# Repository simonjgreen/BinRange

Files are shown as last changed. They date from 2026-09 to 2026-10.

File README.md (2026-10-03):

# BinRange

The calendar says it's bin night. Have the bins actually made it to the kerb?

BinRange gives each bin a battery-powered UWB tag. A fixed anchor measures its
distance and publishes per-tag telemetry to Home Assistant over MQTT. Moving
bins report frequently; stationary bins check in slowly. Home Assistant can
combine that physical evidence with collection dates to show what needs attention.

Collection scheduling for the Home Assistant automations leverages the brilliant
[Waste Collection Schedule](https://github.com/mampfes/hacs_waste_collection_schedule)
integration, available through [HACS](https://hacs.xyz/). It supplies the collection
calendar; BinRange supplies the bin's movement, distance and health.
A [configurable reminder example](examples/home-assistant/README.md) combines the
calendar with fresh Home and observed or presumed Out states for put-out and bring-in notifications.
The optional [tipping package](examples/home-assistant/README.md#tipping-triggered-emptying-messages)
adds the emptying message below when tipping-capable tag and anchor firmware are
installed: a tilt beyond 90 degrees is assumed emptied, and due bins confidently
Out are grouped over 60 seconds. Scheduled reminders remain the fallback.

## Phone reminders

**Bins out tomorrow**

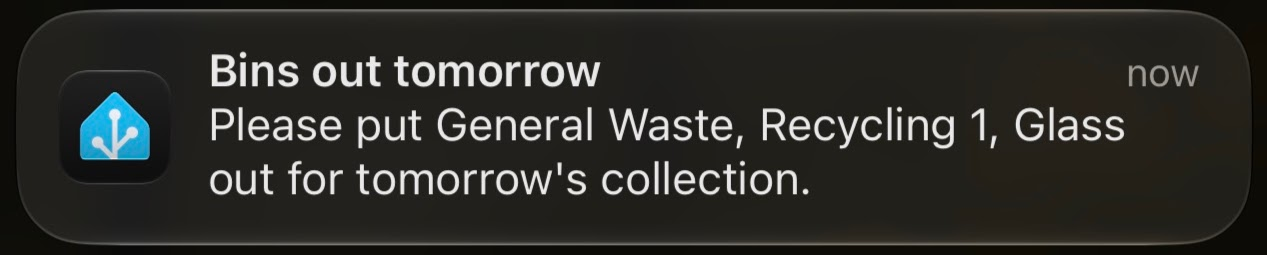
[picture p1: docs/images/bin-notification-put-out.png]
Home Assistant notification reminding you to put General Waste, Recycling 1 and Glass out for tomorrow's collection


**You have still not put the bins out!**

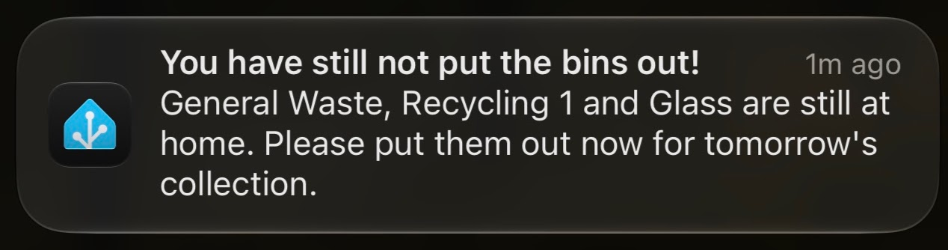
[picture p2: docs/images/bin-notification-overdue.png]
Home Assistant notification warning that General Waste, Recycling 1 and Glass are still at home and need putting out


**The bins have just been emptied**

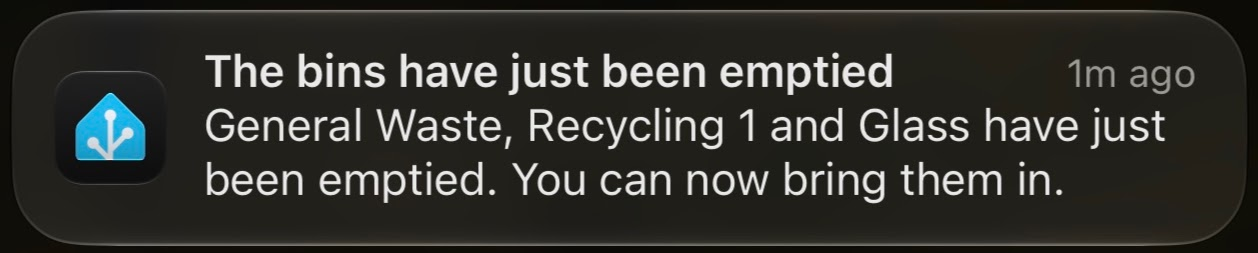
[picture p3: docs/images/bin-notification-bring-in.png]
Home Assistant notification saying General Waste, Recycling 1 and Glass have been emptied and can now be brought in


## The hardware

The main anchor is now wall mounted in its enclosure, all six bins have tags,
and the Home Assistant setup is in use.

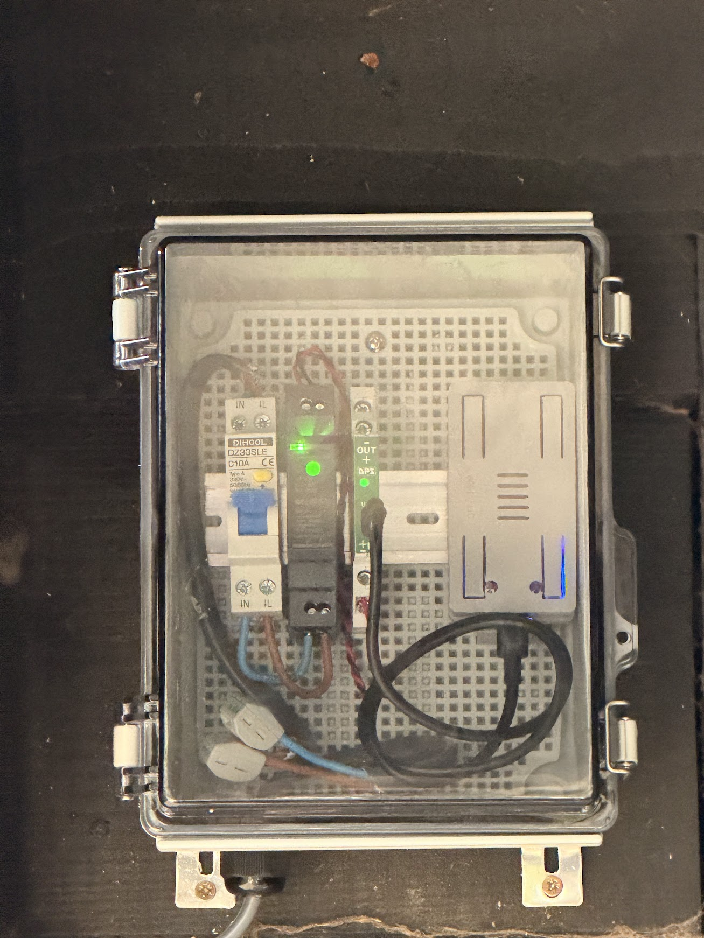
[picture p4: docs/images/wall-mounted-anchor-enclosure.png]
Installed BinRange anchor in its printed case, mounted alongside the power components inside a clear-lidded wall enclosure


*The installed anchor enclosure, photographed by the project owner.*

The anchor has a custom printable case; the battery tags attach to the bins.
These renders show the accepted **v7.1.0 WROVER case**, using the actual print
meshes. Colours and surface finish are illustrative.

| Closed case | Inside the case |
| --- | --- |
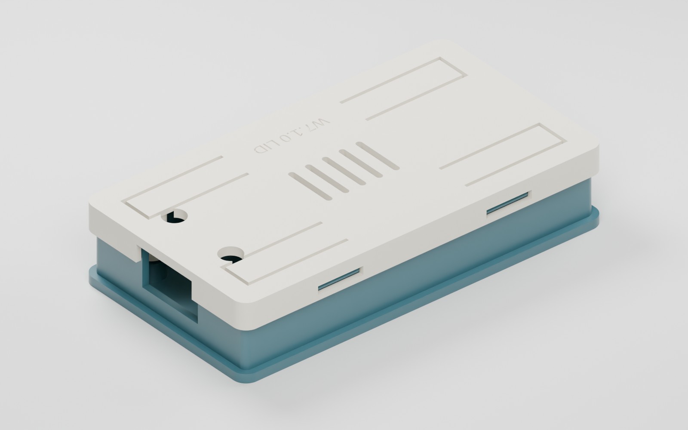
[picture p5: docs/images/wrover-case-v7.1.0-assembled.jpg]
Studio render of the assembled WROVER case, with a petrol-blue base and a warm light lid
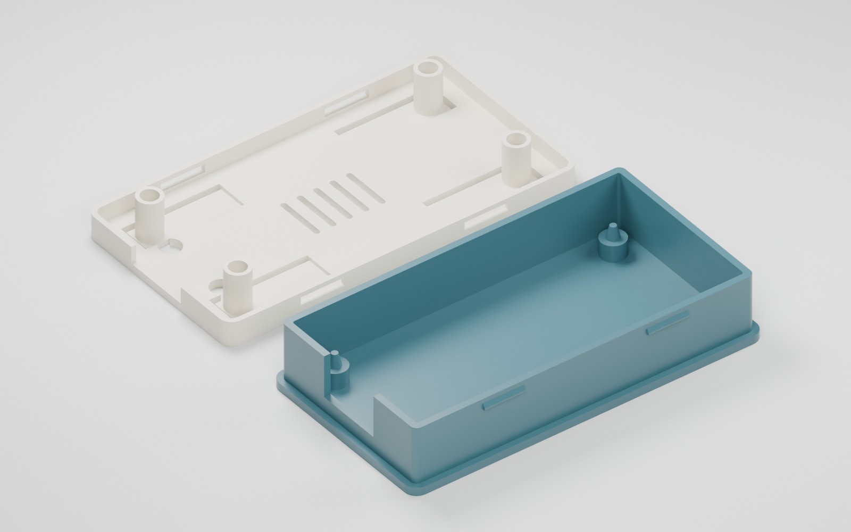
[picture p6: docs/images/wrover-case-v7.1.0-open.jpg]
Studio render of the separate base and lid showing the PCB locating cones, spring supports and ventilation slots
|  |  |

[Case design, version history and print downloads](hardware/wrover-case/README.md).
The separate v7.2.0 DIN rail variant remains experimental.

Installed KKM K4W tags, shown on three different bins:

| Under a wheelie-bin rim | On a food caddy | Under a brown-bin rim |
| --- | --- | --- |
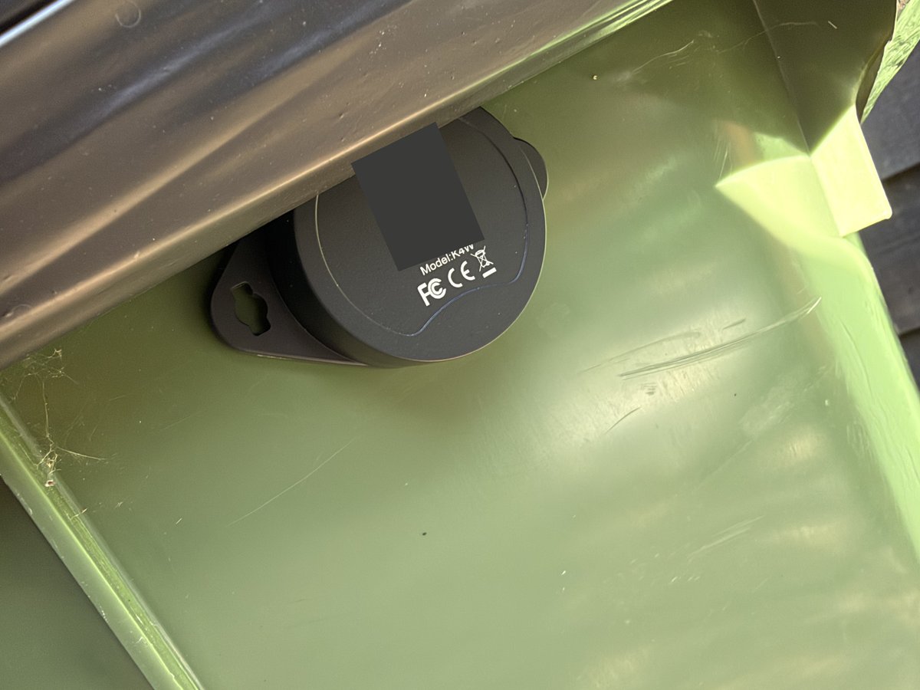
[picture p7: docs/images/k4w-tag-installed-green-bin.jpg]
K4W tag mounted beneath the rim of a green wheelie bin
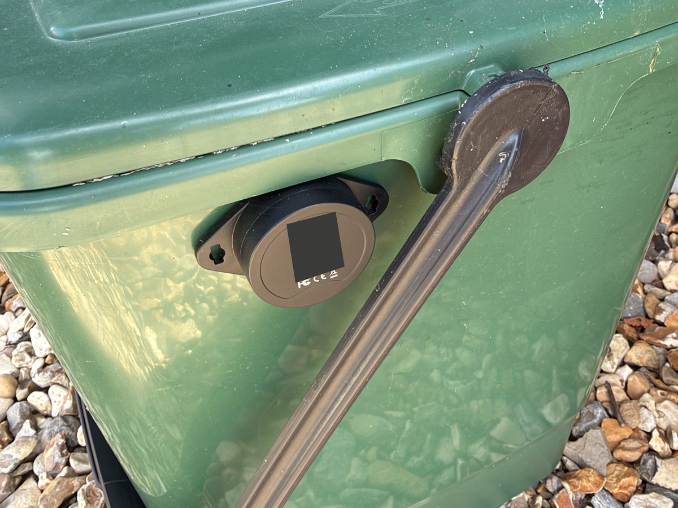
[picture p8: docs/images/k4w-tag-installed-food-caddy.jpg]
K4W tag attached to a green food caddy near its carrying handle
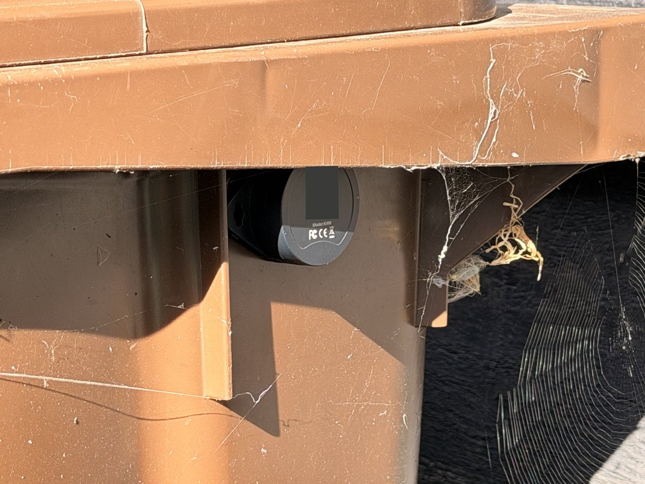
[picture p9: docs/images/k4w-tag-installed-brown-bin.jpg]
K4W tag mounted below the rear rim of a brown wheelie bin
|  |  |  |

| Anchor board | The installation |
| --- | --- |
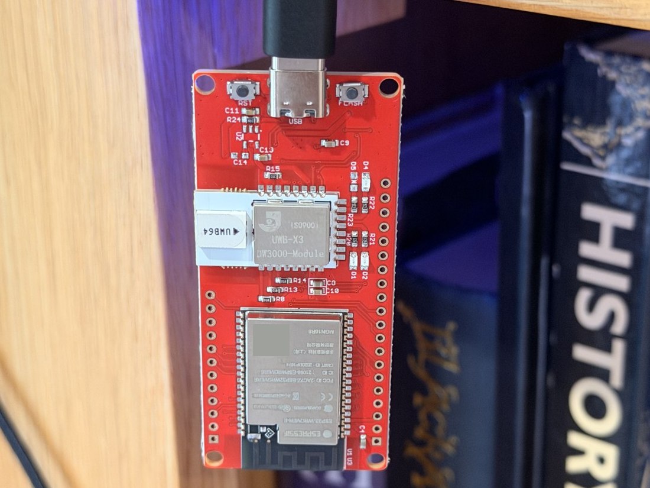
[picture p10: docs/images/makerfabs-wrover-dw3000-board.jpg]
Makerfabs ESP32-WROVER anchor board with USB connected, DW3000 radio module and UWB antenna visible
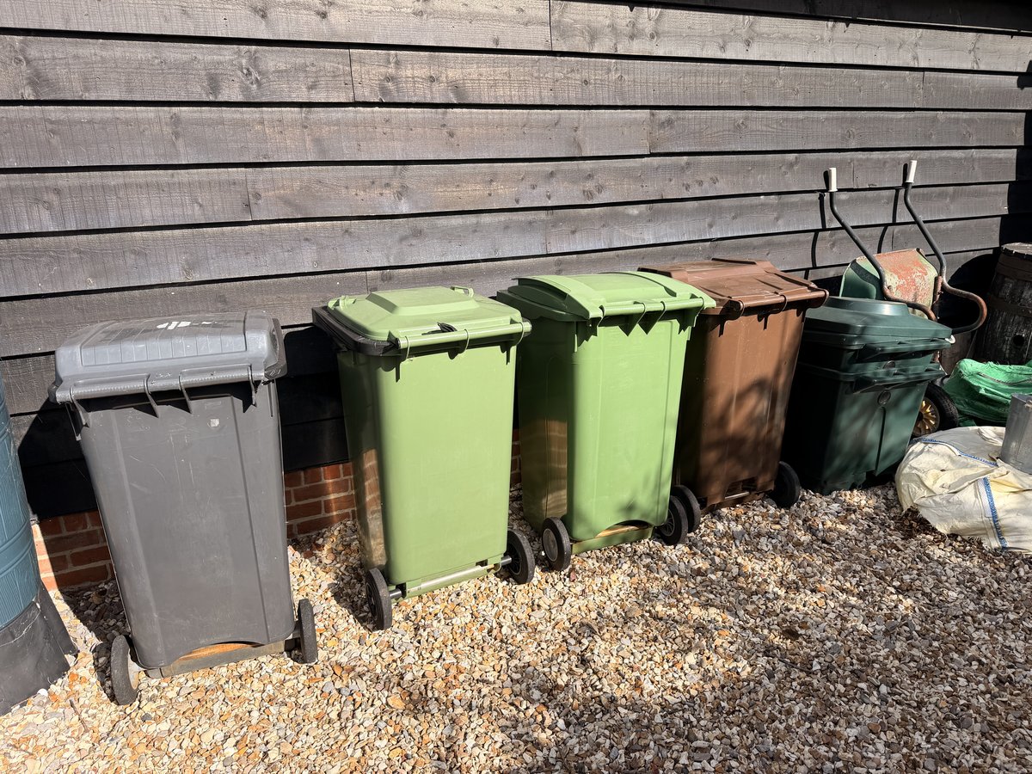
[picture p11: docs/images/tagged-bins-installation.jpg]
A row of household bins in the outdoor installation
|  |  |

*Real installation and development-board photos. Visible device QR codes and
identifiers are obscured; published copies contain no embedded metadata. Mounting
photos document the prototype, not a weatherproofing or coverage guarantee.*

## See it working

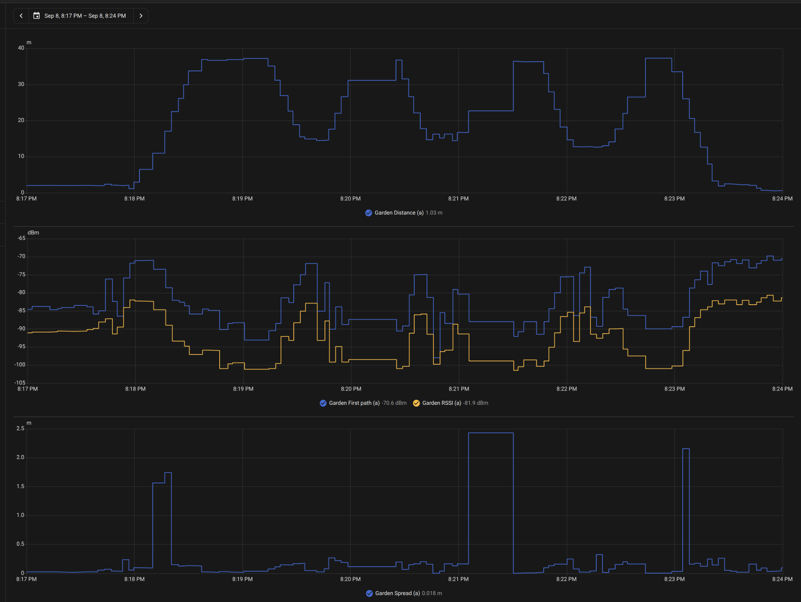
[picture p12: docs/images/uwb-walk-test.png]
UWB outdoor walk: distance rises and falls, with first-path, RSSI and range-spread traces


*Real development walk-test capture using two WROVER boards. Reliable readings
reached roughly 30 m in that setup, with intermittent readings beyond it.
This is not a guaranteed range for a packaged tag or a mounted bin.*

<details>
<summary>Test-phase web interface: live range, link diagnostics and radio tuning</summary>

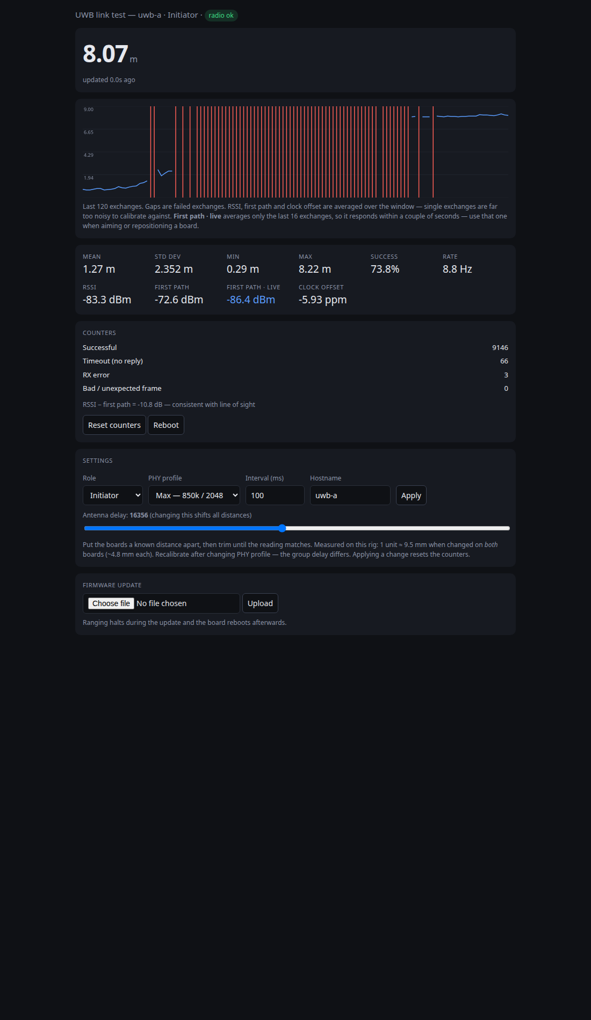
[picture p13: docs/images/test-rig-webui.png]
Early test-rig web interface showing measured distance, exchange history, signal diagnostics and configurable radio settings


*Historical SS-TWR test interface, not the current deployment UI. Its success
percentage and signal interpretation are test-rig diagnostics—not an end-to-end
delivery guarantee or a validated obstruction detector.*

</details>

The important distinction is between **a bin that is home** and **a bin whose
last known reading was home**. Stale data stays visible as stale; silence must
not be mistaken for a bin being put out or brought back. Once a departure has
been observed, location can remain Out through lost reception until a fresh
Home reading confirms its return; reception health remains separate.

## How it fits together

```text
Battery tags ──UWB──> Fixed anchor ──MQTT──> Home Assistant
    ▲                    │                     ▲
    └── signed BLE OTA ──┘                     │
                                 Waste Collection Schedule
```

- **Tags:** KKM K4W, nRF52833 + DW3110 + LIS3DH; custom Zephyr firmware.
- **Anchor:** Makerfabs ESP32-WROVER / DW3000; custom Arduino firmware with MQTT,
  local web administration and signed-tag-update delivery.
- **Home Assistant:** one device per tag plus anchor diagnostics; separate daily
  status and technical monitoring views.
- **Maintenance:** signed application updates, local health confirmation and
  rollback; SWD remains the first-installation/rescue path.
- **No ESPHome component or additional BinRange server.** Ranging does not depend
  on the MQTT broker or Home Assistant being available.

## Status and limitations

This is an **experimental, working field prototype**, not a turnkey product.
A six-tag installation is in use, with the anchor wall mounted, tags on all bins
and Home Assistant configured. Multi-week battery life, installed coverage and
unattended BLE maintenance still need longer-term field evidence.

Default tag behavior is immediate motion reporting, about 5 s while moving,
settling after 30 s quiet, and a 10 min stationary check-in. Motion sensitivity
is tunable; missing-check-in monitoring is separate from short-term range
freshness. The initial absence threshold is six hours. Paired tags expose
stationary and moving check-in interval controls in Home Assistant; the anchor
applies them over authenticated Bluetooth and verifies the saved values.
See [check-in interval controls](docs/mqtt.md#changing-tag-check-in-intervals).

One anchor measures **distance, not direction or coordinates**. A Home/Out
distance threshold is site-specific; it cannot distinguish equal-radius places.
Metal, bodies, orientation and mounting affect coverage. Battery voltage is
measured; any percentage derived from it is an estimate, not a fuel gauge.
Do not infer months of battery life from a short voltage trace.

## Build your own

Start with [the setup guide](docs/getting-started.md), then the relevant firmware
instructions. You will need an appropriate UWB anchor, compatible tags, an SWD
programmer, a local MQTT broker and Home Assistant. Review the exact board pinout
and use your own credentials, tag identities and signing key.

| Reference | Purpose |
| --- | --- |
| [Getting started](docs/getting-started.md) | Prerequisites, setup sequence and local configuration |
| [Hardware](docs/hardware.md) | Components, wiring, battery and motion constraints |
| [Printable anchor case](hardware/wrover-case/README.md) | Case renders, version status, source and print files |
| [MQTT / Home Assistant](docs/mqtt.md) | Topics, adoption, freshness and scheduling integration |
| [Collection reminder example](examples/home-assistant/README.md) | Placeholder YAML, phone-group setup and put-out/return reminder behavior |
| [Signed tag build and recovery](firmware/k4w-tag/BUILD.md) | SDK, partitions, signing and safe installation |
| [BLE update contract](docs/tag-updates.md) | Authentication, persistence and recovery invariants |
| [Nesso SWD probe](firmware/nesso-probe/README.md) | Optional programmer build and wiring |
| [Findings](docs/findings.md) | Reusable measured results and their limitations |
| [Roadmap](docs/current-work.md) | Remaining project acceptance work |

## Repository hygiene

The active firmware is in `firmware/anchor` and `firmware/k4w-tag`, with the
shared radio driver in `firmware/shared`. The Nesso probe and `scripts/` contain
programming, recovery and host-test tooling. `firmware/tag-emulator` is a bench
DS-TWR test peer; `firmware/test-rig` is the frozen early SS-TWR experiment.
Neither is required on the installed bins. Older enclosure versions and their
verified archive are retained as design history, with their status recorded in
the [case index](hardware/wrover-case/README.md).

This repository contains reusable source, documentation, synthetic test
identities and selected screenshots. Local addresses, household calendars,
physical tag/casing registers, credentials, signing keys, private captures and
provisioned firmware belong in ignored local storage—not Git.

On an existing working installation, consult ignored
`local-backups/deployment/docs/current-work.md` for its private operating plan
before touching devices. Public examples are not deployment instructions for
someone else's hardware. Do not blindly replay first installation on a paired tag.

BinRange's original code and documentation are licensed under the
[MIT License](LICENSE). Third-party components retain their own licences and
vendor notices. See [third-party notes](docs/third-party.md).

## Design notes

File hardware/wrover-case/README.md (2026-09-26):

# WROVER case — working design v7.1.0

**Working design: [v7.1.0](versions/v7.1.0/README.md), accepted by the user. Both halves remain compatible with v7.0.0.**

[Complete v7.1.0 print package](releases/wrover-case-v7.1.0.zip) · [Full base STL](versions/v7.1.0/exports/wrover-case-v7.1.0-base.stl) · [Full lid STL](versions/v7.1.0/exports/wrover-case-v7.1.0-lid.stl) · [OpenSCAD source](versions/v7.1.0/wrover-case-v7.1.0.scad) · [Preview](versions/v7.1.0/exports/wrover-case-v7.1.0-layout.png)

The user reports v7.0.0 as “really good” and has accepted v7.1.0, with wider locating cones and centred vents, as the working design. No quantified retention, thermal or endurance results have been reported.

| Assembled v7.1.0 | Base and lid interior |
| --- | --- |
| Assembled WROVER case rendered from the v7.1.0 print meshes | Open v7.1.0 case showing PCB locating cones and lid springs |

*Renders of the actual STL geometry; colours and surface finish are illustrative.
The board is omitted to show the case details. [Renderer](tools/render_readme.py).*

**DIN rail candidate: [v7.2.0](versions/v7.2.0/README.md)**, experimental. It is the v7.1.0 base on a dovetail plinth with a separate snap-on TS35 clip. The lid is unchanged. [Base](versions/v7.2.0/exports/wrover-case-v7.2.0-base.stl) · [DIN clip](versions/v7.2.0/exports/wrover-case-v7.2.0-din-clip.stl) · [Print package](releases/wrover-case-v7.2.0.zip)

## Version history

Old names have been normalised without changing the archived geometry. The historical v5.1 is now v5.1.0, for example.

| Version | Closure | Physical result | Base compatibility |
|---|---|---|---|
| v1.0.0 | Original screws | Original board fit check passed; standalone source not found | Not established |
| [v2.0.0](versions/v2.0.0/README.md) | Recessed M2.5 screws | Superseded small-hardware approach | v2 only |
| [v3.0.0](versions/v3.0.0/README.md) | M2 bolts and nuts | Rejected: PLA fits and small hardware impractical | v3 only |
| [v4.0.0](versions/v4.0.0/README.md) | External flexible clips | Pegs and PCB springs worked; lid loose | v4 only |
| [v5.0.0](versions/v5.0.0/README.md) | Internal lip, 0.6 mm hooks | Good fit; insufficient retention | v5 base |
| [v5.1.0](versions/v5.1.0/README.md) | 1.0 mm hooks | Better retention; still pulls off easily | v5 base |
| [v5.2.0](versions/v5.2.0/README.md) | 3.0 mm full-wall hooks | **Failed: both roots broke on insertion** | v5 base |
| [v6.0.0](versions/v6.0.0/README.md) | Torsion-arm catches | CAD checks only; untested, superseded by research direction | v5 base |
| [v7.0.0](versions/v7.0.0/README.md) | Overlapping shells, four shallow beads | **User-tested: “really good”; two refinements requested** | v7.0.0 / v7.1.0 / v7.2.0 halves |
| [v7.1.0](versions/v7.1.0/README.md) | Same closure; 3 mm cone roots, centred vents | **Working design: accepted by user** | v7.0.0 / v7.1.0 / v7.2.0 halves |
| [v7.2.0](versions/v7.2.0/README.md) | v7.1.0 plus dovetail plinth and snap-on TS35 DIN clip | Experimental: CAD checks only | Any v7 lid; lid unchanged |

## Folder and naming rules

```text
wrover-case/
  README.md                  Start here: working version, history, compatibility
  versions.json              Machine-readable version/status index
  versions/v7.1.0/            One self-contained design snapshot
    README.md                Printing, assembly, evidence and limitations
    status.json              Physical status and part hashes
    wrover-case-v7.1.0.scad   Versioned source
    verify_geometry.scad     Collision/engagement checks
    verify_geometry.py       Check runner
    geometry-results.json    Recorded results, not a physical-test certificate
    exports/
      wrover-case-v7.1.0-base.stl
      wrover-case-v7.1.0-lid.stl
      wrover-case-v7.1.0-layout.png
  releases/                  Versioned distribution ZIPs
  tools/                     Shared mesh validation
  sources/                   Board dimensions and original PCB evidence
  research/                  Maker references and design findings
  archive/                   Verified, byte-preserved original file tree ZIP
```

- Use `vMAJOR.MINOR.PATCH`, numerically sorted. Increment **major** for a new closure architecture or incompatible mating geometry; **minor** for a compatible geometry variant; **patch** for corrected exports or manufacturing details with the same intended fit. A patch is still a new printable file, never a silent overwrite.
- Treat delivered sources and print meshes as snapshots. Store subsequent geometry under a new version. Status/physical feedback may be updated without changing geometry.
- Use `wrover-case-v<version>-<part>.<extension>` for printable/downloadable files. Do not use floating `base.stl`, `lid.stl`, `latest`, `final`, or an unqualified `trial` filename.
- Each version directory includes its complete matching base/lid pair, even when a base is unchanged. Equal base hashes document actual reuse. The compatibility table overrides assumptions based on version numbers; historical v6 retained the v5 base.
- Record physical status separately from version: working, experimental, user-tested, partial-success, failed, rejected or superseded. A newer number is not proof of improvement.
- Produce full-case candidates. Small closure coupons are historical only, following the user's printing preference.

## Preserved history

All 67 previously present case files (excluding Python bytecode and the unchanged board/research directories) were preserved and SHA-256 verified in [the original-layout archive](archive/README.md) before reorganisation. This includes prior ZIPs, duplicated aliases, small coupons, previews and historical instructions. Canonical historical source/STL copies retain their original bytes; verification includes were updated to the renamed sources.

The unversioned `case.3mf` and `base.png` could not be assigned a reliable version and remain labelled as unverified historical assets in the archive. No v1 source has been invented. The board evidence remains in `sources/`.

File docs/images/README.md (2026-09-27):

# README hardware images

The public hardware gallery uses the following derivatives. Private originals
and Live Photo videos are not included here.

| Asset | Subject / source |
| --- | --- |
| `wall-mounted-anchor-enclosure.png` | User-supplied photo of the installed anchor enclosure, preserved unchanged |
| `wrover-case-v7.1.0-assembled.jpg` | Accepted v7.1.0 base/lid STL meshes, assembled |
| `wrover-case-v7.1.0-open.jpg` | The same meshes, separated to show their interiors |
| `k4w-tag-installed-green-bin.jpg` | User-supplied installation photo, cropped |
| `k4w-tag-installed-food-caddy.jpg` | User-supplied installation photo, cropped |
| `k4w-tag-installed-brown-bin.jpg` | User-supplied installation photo |
| `tagged-bins-installation.jpg` | User-supplied installation overview |
| `makerfabs-wrover-dw3000-board.jpg` | Existing local development-board photo, cropped |

The case renders are generated with
[`render_readme.py`](../../hardware/wrover-case/tools/render_readme.py), using
Blender 4.5.3, soft studio lighting and illustrative polymer materials. They
preserve the printable geometry. They are not photographs of a manufactured
case. The board is omitted.

The seven JPEGs have photos at most 1200 × 900 pixels and renders at 1600 × 1000.
They are optimized progressive JPEGs. Orientation is baked into the pixels before
export. Each image is copied into a fresh RGB image and encoded without EXIF,
GPS, XMP, IPTC, comments, embedded thumbnails or source colour profiles.

The wall-mounted enclosure photo is the original 1307 × 1742 PNG. Its only PNG
chunk types are IHDR, IDAT and IEND; it has no embedded metadata. The supplied
pixels were inspected and contain no readable device identifiers needing masking.

Readable device QR codes and identifiers are covered with opaque masks before
resizing. The food-caddy crop also excludes the label on its lid. Model names
and regulatory markings remain where possible. Original filenames, capture
timestamps, device identities and local source paths are not recorded here.

For future additions, inspect the pixels as well as metadata: strip metadata,
check for labels, faces and addresses, export a fresh derivative, then verify
the result and its README link. Existing walk-test screenshots are separate
historical assets and are not part of this photo export.

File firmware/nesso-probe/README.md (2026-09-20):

# Nesso SWD probe

Optional standalone programmer/recovery jig; not a deployment dependency.

Upstream: [cmsis_dap_tcp_esp32](https://github.com/bkuschak/cmsis_dap_tcp_esp32),
pinned `cc547237006452be22fcf03e25f84cffb0de6a65` (Apache-2.0).
From this directory:

```sh
git clone https://github.com/bkuschak/cmsis_dap_tcp_esp32.git upstream
git -C upstream checkout --detach cc547237006452be22fcf03e25f84cffb0de6a65
pio run -e nesso
python ../../scripts/test_nesso_config.py
NESSO_SDKCONFIG=sdkconfig.nesso python ../../scripts/test_nesso_config.py
```

The upstream checkout is ignored; preserve its licence. Platform espressif32
6.11.0 selects ESP-IDF 5.4.1. Local compatibility code maps newer help-command
deregistration to that API; `-ftls-model=local-exec` avoids RISC-V GOT TLS sections.

No Wi-Fi credentials are compiled in. Provision using the USB console's `wifi`
command and reboot; do not log password-bearing traffic. TCP 4441 is trusted-LAN
only. A blank display is normal for this headless firmware.

## Wiring and power

Header numbers follow Arduino's diagram, not M5Stack's reversed table:

| Tag pad | Nesso header |
| --- | --- |
| GND | 1 |
| CLK | 5 / GPIO6 |
| DIO | 3 / GPIO7 |
| VDD | 7 / 3.3 V |

Remove the tag battery. Check polarity and voltage before attachment; never use
5 V or BAT pins for the tag. Power Nesso fully off before rewiring.
Nesso is battery-backed: unplugging USB alone does not cut target power.
For a coordinated power-cut test, removing all clip contacts disconnects the tag.

Back up and identify your Nesso before replacing its original firmware.
Existing local backups/serials are private, not a generic recovery image.
Tag first installation must deliberately handle read protection and identity;
never infer blank flash from an unlit LED.

## Host transport

OpenOCD needs the CMSIS-DAP TCP backend. Tested:
Espressif `v0.12.0-esp32-20260831`; older distribution builds may lack it.
`openocd-nrf52.cfg` sets 100 kHz after target defaults and binds host control
listeners to localhost. The config itself contains no erase/programming calls.

From repository root, explicitly select your probe:

```sh
python scripts/dap_relay.py --probe PROBE_IP
```

Point OpenOCD at relay `PROBE_IP=127.0.0.1`; set `cmsis-dap quirk enable`
and `cmsis-dap tcp min_timeout 1000` before init. The conservative relay allows
one request/64-byte packet and exits when the debugger disconnects.
A transport failure never authorizes replaying a flash.

## First-install command

`scripts/k4w_program.py` owns its relay/debugger and performs one guarded first
installation. It is **not an updater** for an already commissioned tag.

Use the SDK Python with intelhex, pyelftools and imgtool dependencies.
This example uses synthetic casing identifiers and performs offline checks only:

```sh
python scripts/k4w_program.py \
  --tag b110 --name 'Example bin' --mac 020000000010 --serial 100010 \
  --photo /absolute/path/to/your-casing-photo.jpg \
  --profile /absolute/path/to/private-programmer.json --check
```

Replace every identity/photo with the actual new unit. Optional `--qr` must be
independently decoded. `--check` creates no record and connects to no hardware.
Live installation additionally requires `--erase-factory`,
`--battery-disconnected` and `--confirm-casing MAC/SERIAL`. These assertions
must reflect a real physical check; they are not proof of board/casing identity.
Stop other debugger/relay sessions and leave the tag in place until closure.

Private profile fields:

- `probe_ip`, expected `probe_serial`, OpenOCD executable.
- Matching `build_dir`, `imgtool`, private signing-key path `key`.
- Required nonempty `protected_hardware_ids`: unique lowercase 16-hex chip IDs
  never eligible for first installation. Missing/malformed values fail closed.
- `files` and `sha256` mappings for exactly `boot_hex`, `boot_bin`,
  `boot_elf`, `app_hex`, `app_bin`, `app_elf`.

Use deliberately verified artifacts; the tool never selects an arbitrary latest
build. It reserves a private casing record before mutation, rejects existing
casing/UWB/name/chip identities and unresolved previous attempts. Read-protected
factory chips cannot expose DEVICEID before recovery, so physical selection
remains essential. Probe serial is checked before erase; chip guards run as soon
as readable and before later writes.

Full NFC→GPIO/boot/app readbacks, signed-image confirmation, local health and
identity persistence are checked. PIN/outputs remain private. Adoption and BLE
pairing are separate steps.

**On failure, inspect rather than rerun.** Do not delete an existing record just
to bypass the guard. Determine actual hardware state before any continuation.
See [signed recovery](../k4w-tag/BUILD.md).

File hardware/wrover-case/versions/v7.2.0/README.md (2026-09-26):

# WROVER case v7.2.0 — DIN rail mount

**Status: experimental. CAD checks only; not yet printed.**

v7.2.0 is the accepted v7.1.0 case with a DIN rail mount added to the underside of the base, the larger half. The enclosure, closure beads, PCB cones and PCB springs are unchanged. The lid STL is byte-identical to v7.1.0 and still reads `W7.1.0 LID`. Any v7.0.0 or v7.1.0 lid fits this base.

Print files:

- `exports/wrover-case-v7.2.0-base.stl`: v7.1.0 base on a 3 mm dovetail plinth, marked `W7.2.0 BASE` underneath
- `exports/wrover-case-v7.2.0-lid.stl`: unchanged v7.1.0 lid
- `exports/wrover-case-v7.2.0-din-clip.stl`: separate snap-on clip for TS35 × 7.5 mm (EN 60715) top-hat rail

The closed case is now 86 × 46.6 × 20.6 mm. The clip holds the case front 11 mm off the rail face, so the case sits about 39 mm proud of the mounting panel.

## Why a separate clip

A clip moulded into the floor would stop the base printing flat and would need support under the whole case. Instead, the base gets a flat 3 mm plinth with two dovetail grooves cut into its underside. The clip prints on its side, so its spring and hooks are built from layer-parallel walls and flex along the layer lines rather than across them. Neither part needs supports. No screws, glue or metal parts are used.

## How it mounts

It snaps on and off anywhere along the rail, like a breaker. You never slide it on from the rail end.

The rail runs across the case width, along Y. On a level rail the case stands with its long axis vertical and takes about 2.6 DIN modules (46.6 mm) of rail.

- **Fixed hook** at the far end, away from the USB. Hook it over the top rail edge first.
- **Sprung latch** at the USB end. A five-beam serpentine spring lets the latch block slide outward. Its lower face is a 44° ramp, so rotating the case onto the rail snaps it on. With the latch at the bottom, the USB end faces down.
- **Pull tab**: a lip stands 2.5 mm beyond the USB end of the case. To remove the case, put a small flat screwdriver or a fingernail in the gap between the lip and the case, pull the lip outward about 1.7 mm, and tilt the case off the rail.

## Clip to base

1. Slide the clip into the grooves from the open side of the plinth, with the dovetails leading. A shallow ramp at the plinth edge presses the detent finger down.
2. Push the clip until it stops at the blind groove end. The finger's ridge drops into a pocket in the plinth and the clip clicks into place, centred under the case.
3. The pocket's back edge is a 45° ramp. The clip is held against vibration and casual knocks, and comes out with a firm pull along the rail direction. This is a detent, not a positive lock.

Fit the clip to the base before putting the case on the rail. Once the case is on the rail, the rail can't stop the case sliding along the clip; only the detent does.

## Key dimensions

| Feature | Value |
|---|---|
| Rail | TS35 × 7.5, 1.0 mm lip |
| Hook reach behind the rail lip | 1.5 mm each side |
| Clearance behind the lip | 0.40 mm fixed hook (to allow rocking on), 0.25 mm latch |
| Latch travel to clear the rail edge | 1.7 mm (release envelope checked) |
| Serpentine | 5 beams, 1.0 mm thick, about 9 mm free length, 1.2 mm gaps |
| Dovetails | 8 mm neck, 2.4 mm deep, 30°, 0.2 mm clearance per face |
| Detent | 0.8 mm ridge on a 1.2 mm finger, 1.0 mm deep pocket |
| Clip | 67.3 mm along the case, 26 mm along the rail |

## Printing

- **Base**: floor down, as for v7.1.0. The groove roofs and the detent pocket bridge about 11 mm and 3 mm respectively; no supports. Check the first layers: elephant's foot will narrow the dovetail mouths.
- **Clip**: lay it on its side, profile face down, 26 mm tall. PLA works, and PETG is the kinder material for the latch spring. Use at least 3 walls so that the 1.0 mm spring beams and the 1.2 mm detent finger print solid. No supports; nothing overhangs.
- **Lid**: unchanged from v7.1.0.

## Verification and limits

`verify_geometry.py` reruns all eleven v7.1.0 closure and PCB checks against the unchanged upper base, plus eleven DIN checks:

- The seated clip clears the base.
- The whole slide-in path is clear, with the detent ridge sprung down.
- Overtravel hits the blind groove end.
- Backing the clip out 0.6 mm meets the detent ramp.
- The seated clip clears the rail.
- Both hooks overlap the rail lip on a pull-off attempt.
- With the latch pulled 1.7 mm, the rail passes it on a straight-line path.
- The pulled latch doesn't hit the rigid clip body or the case.
- Mid-rail fitting, checked in reverse as removal: with the latch pulled, the case rotates about the fixed hook to 10° without touching the rail.
- At 10°, with the latch at rest, the case shifts 1.8 mm towards the fixed end and lifts straight off. At 6° and 8° it still collides, so it needs a proper tilt.

The results are in `geometry-results.json`.

These are rigid-body clearance checks. The spring beams are excluded from the pulled-latch check because they bend in service. Snap-on force, spring strain, detent hold and the real hand motion have not been calculated or measured. The tilt checks cover one rigid path through the rail's cross-section. The 1.0 mm beams take roughly 0.33 mm of deflection each at full latch travel. That is a modest bending strain for PLA, but it is an estimate, not a test.

Things to check on the first print:

- The clip slides into the base with hand pressure and clicks home.
- It snaps onto a real rail and comes off with the pull tab.
- The case doesn't rattle on the rail.

## Rebuild

From this directory:

```sh
openscad -o exports/wrover-case-v7.2.0-base.stl -D 'part="base"' wrover-case-v7.2.0.scad
openscad -o exports/wrover-case-v7.2.0-din-clip.stl -D 'part="din_clip"' wrover-case-v7.2.0.scad
python3 ../../tools/verify_meshes.py exports/wrover-case-v7.2.0-base.stl exports/wrover-case-v7.2.0-lid.stl exports/wrover-case-v7.2.0-din-clip.stl
python3 verify_geometry.py
```

The lid is copied from v7.1.0 rather than re-exported. OpenSCAD 2021.01 STL output isn't byte-reproducible, and copying keeps the equal hash as evidence of reuse. Setting `din_mount = false` rebuilds the plain v7.1.0 base geometry.

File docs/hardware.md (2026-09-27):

# Hardware reference

BinRange currently targets a Makerfabs ESP32-WROVER/DW3000 anchor and KKM K4W
nRF52833/DW3110 tags with a LIS3DH accelerometer. Verify the actual board revision
and populated parts before adapting this pinout. Vendor-confidential schematics,
purchase records and physical tag identifiers are not distributed.

## Tag components and pins

The nRF52833 has 512 KiB flash / 128 KiB RAM. The tested DW3110 reported radio
ID DECA0302; LIS3DH responded at I2C 0x19 with WHO_AM_I 0x33.
SWD uses CLK, DIO, GND and VDD.

| Signal | nRF pin |
| --- | --- |
| DW3110 SCLK / MOSI / MISO | P0.31 / P0.30 / P0.28 |
| DW3110 CS / IRQ / reset | P0.02 / P0.03 / P0.29 |
| Accelerometer SCL / SDA | P0.09 / P0.20 |
| Accelerometer INT1 / INT2 | P1.09 / P0.11 |
| Accelerometer CS / SDO | P0.15 / P0.17 |
| KEY, active low | P0.04 |
| LED1 / LED2 | P0.05 / P0.10 |

P0.09/P0.10 are NFC-capable. Accelerometer operation on the tested revision
required explicit one-time NFCPINS configuration at 0x1000120c to 0xfffffffe.
This is a persistent hardware configuration change, not an ordinary OTA setting.
Verify the intended bit change and full UICR readback. Normal firmware must not
silently modify UICR; restoring a cleared bit needs erase/recovery.
See Nordic [pin configuration](https://docs.nordicsemi.com/r/bundle/ps_nrf52833/page/nfc.html)
and [NVMC](https://docs.nordicsemi.com/r/bundle/ps_nrf52833/page/nvmc.html).

Physical KEY behavior must be checked before relying on it for maintenance.
KEY/LED1 multiplex connector UART labels; do not assume an independent spare UART.

## Identity and safe programming

Keep a private register of casing label/QR, immutable FICR chip ID, chosen UWB ID,
firmware-selected Bluetooth address and bin name. The printed vendor MAC need
not be the on-air address; a generic BLE advertisement name is not identity.
A QR code or serial is not automatically a pairing PIN.

Verify the physical target before any write. Decide deliberately whether to back
up factory firmware before first installation; protected flash may require
destructive recovery. Never replay first-install erase on a commissioned tag.

**Never connect the battery and programmer VDD simultaneously.** Check polarity
and supply voltage before attachment. The [Nesso probe](../firmware/nesso-probe/README.md)
is battery-backed; unplugging its USB does not necessarily remove tag power.

## Battery and mounting

The tested tag accepts a removable CR2477 cell. Verify its actual battery
specification before use. BAT feeds the MCU/accelerometer supply with bulk
capacitance; UWB has 1.8 V regulation.

Internal VDD sampling needs no spare ADC pin. SAADC uses internal reference and
gain 1/6; the pinned Zephyr input is `NRF_SAADC_VDD` (128), not raw HAL
`NRF_SAADC_INPUT_VDD` (9). The app samples after waking UWB, before ranging.
It does not measure rested open-circuit voltage or minimum pulse sag.

Validate meter agreement and whole-tag idle/active current before estimating
life. A regulated jig voltage is not a battery baseline. Coin-cell percentages
derived from voltage are provisional and affected by load and temperature.

Mount securely, consider antenna orientation and metal/body shadowing, preserve
battery access and verify enclosure sealing. Shelter under a bin lip is not
an ingress-protection rating. Final anchor power should be stable and permanent.

## Accelerometer and low-power constraints

The pinned SDK supports LIS3DH via LIS2DH with dual compatible
`"st,lis3dh", "st,lis2dh"`. Only the former does not instantiate the driver.
See the pinned [RAK5010 example](https://github.com/nrfconnect/sdk-zephyr/blob/fd9204a02d52630660ce8d729945a4dd743feabf/boards/rakwireless/rak5010/rak5010_nrf52840.dts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).
Delta-trigger duration is 0–127 samples at the selected rate, not milliseconds;
threshold units are m/s².

Set `SENSOR_ATTR_CONFIGURATION=0x01` (CTRL2 HPIS1) and read REFERENCE to reset
the high-pass filter. The Kconfig option alone does not enable filtering;
otherwise gravity can retrigger motion. Health checks verify CTRL2.
Current defaults are 250 mg for two samples at 25 Hz. Tune using wheeling,
stationary periods, wind/lid knocks and different orientations—not a universal
"bin moved" assumption. See ST's [datasheet](https://www.st.com/resource/en/datasheet/lis3dh.pdf)
and [motion examples](https://www.st.com/resource/en/application_note/an3308-lis3dh-mems-digital-output-motion-sensor-ultralowpower-highperformance-3axis-nano-accelerometer-stmicroelectro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).

The recovery bootloader's 20 s watchdog runs during CPU sleep. Event/deadline
wakes service it at most 10 s apart; ten-minute reporting does not mean ten
minutes without CPU wakeups. UWB sleeps between attempts; BLE remains slowly
discoverable. Do not disable recovery to reduce power.

Image capacity is 212992 bytes including signing overhead. LTO/local ISR tables
are required by the integrated candidate. Verify each exact signed artifact;
never silently repartition an installed tag. See the [build guide](../firmware/k4w-tag/BUILD.md).

For the tipping classifier in tag 0.2.7+, CTRL2 remains 0x01: the high-pass path
feeds the motion interrupt, while output samples retain gravity (FDS is clear).
No new sensor or interrupt wiring is required. The firmware checks orientation
at 25 Hz during motion/leaning and at 1 Hz while idle; the latter covers slow
rotation below the existing delta-interrupt threshold. Initial upright reference
capture, filtering and event limitations are documented in the
[build guide](../firmware/k4w-tag/BUILD.md#tipping-detection-027).

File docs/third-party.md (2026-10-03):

# Third-party components and publication notes

The project's original code and documentation are licensed under the
[MIT License](../LICENSE). Third-party components retain their own licences
and copyright notices, as described below.

- **Waste Collection Schedule:** collection dates are supplied by
  [mampfes/hacs_waste_collection_schedule](https://github.com/mampfes/hacs_waste_collection_schedule),
  installed separately through HACS. BinRange does not bundle or replace it.
- **DW3000 driver:** adapted Makerfabs/Decawave code lives under
  `firmware/shared/Dw3000` and the frozen test rig. Library metadata declares
  Apache-2.0; individual source files retain Decawave copyright/rights notices.
  Preserve those notices and review upstream terms before redistribution.
- **Anchor stack:** PlatformIO/espressif32, Arduino-ESP32, PubSubClient and
  NimBLE-Arduino are separately obtained dependencies pinned/configured in
  `platformio.ini`.
- **Tag stack:** Nordic nRF Connect SDK, Zephyr, MCUboot and their dependencies
  retain their own licences. The SDK is obtained separately, not vendored here.
- **Optional Nesso probe:** uses
  [bkuschak/cmsis_dap_tcp_esp32](https://github.com/bkuschak/cmsis_dap_tcp_esp32)
  at the pinned revision in its guide; upstream is not committed.
- **Screenshots:** selected project-generated development captures are under
  `docs/images/`; they illustrate testing, not a product guarantee.

Private vendor schematics, purchase paperwork, provisioned binaries, raw local
captures, credentials and signing keys are excluded. Public test fixtures use
synthetic identities rather than real devices.

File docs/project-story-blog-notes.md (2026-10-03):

# BinRange: consolidated project story and blog notes

_Prepared 3 October 2026 from the owner's pasted early UWB discussion, the BinRange discussions, the repository, and documented field findings. This is source material for a blog post, not a claim that every remaining field test has passed._

## The short version

The starting question was simple: the collection calendar knows which bins are due, but it cannot tell whether anyone has actually moved them. Years ago, an attempt to answer that with cheap Bluetooth tags proved frustrating: batteries drained, proximity readings jittered, and the outdoor Home Assistant Bluetooth proxy was unreliable in that installation. Reading about UWB reopened the idea. BinRange then grew from a pair of USB-powered UWB development boards into a working six-bin field prototype. Each bin now carries a battery-powered radio tag; a fixed, powered anchor measures its distance, sends readings to Home Assistant through MQTT, and lets the collection calendar drive reminders. The tags report more often when moved and sleep between occasional stationary check-ins. The anchor can also deliver signed firmware updates to already paired tags over Bluetooth.

The project then acquired two things a bench demonstration could not supply: physical packaging and real collection-day evidence. A sequence of printed case failures led to a screwless overlapping-shell enclosure. An observed garden-bin collection showed that movement, departure, return and tipping could be detected, while radio coverage at the kerb and the calendar connection could still prevent the notifications from firing. Those failures prompted a repaired calendar and a more realistic remembered-**Out** state. A separate review replaced frequent tipping-automation polling with an event-driven timer. The installed system is useful and in service, but battery lifetime, outdoor coverage and unattended maintenance need longer observation.

## What problem we were trying to solve

The practical problem is a mismatch between **schedule** and **physical state**. A calendar can say “General Waste tomorrow”; it cannot answer “is the General Waste bin still by the house?” Nor does a lack of radio contact automatically mean the bin has moved. The intended outcome became a household view that shows the bins' status, calls attention to bins still Home before collection, and reminds us to bring them back afterward. Later, the desired “they have just been emptied” message added a different physical question: can the system recognise a tip rather than merely a move?

The agreed fleet is six physical bins: Garden, Recycling 1, Recycling 2, Compost, General Waste and Glass. Calendar categories do not map one-to-one to hardware: “Recycling” covers both recycling bins, and the “Food” collection maps to Compost. This mapping is a useful detail for the blog because it shows why calendar names alone could not serve as device identities.

## Before BinRange: why UWB, and what was rejected

The original BLE version tried to infer whether a bin was nearby from cheap tags and an outdoor Home Assistant BLE proxy. The owner reported three problems: fast battery consumption, inconsistent/jittery readings, and proxy reliability at the time it was built. The UWB discussion reframed the measurement from received signal strength to radio time of flight. The aim was a robust **home zone**, not a map of the garden or the centimetre-level tracking of runners that inspired the research question.

The first research answer actually preferred a wired reed or Hall sensor with a passive magnet **if** each bin had a fixed berth. The owner ruled that out immediately: the bins do not dock in consistent or precise places. That constraint, together with the desire to distinguish individual bins, made a radio range measurement worth testing. One anchor near storage was the proposed starting point; a second was only a contingency if the storage and kerb positions had similar distances or the link was obstructed. Three-anchor triangulation was unnecessary for the household question.

There was a separate conversation about conventional UWB positioning: three well-spaced anchors are the geometric minimum for 2D, four for 3D, and clustering anchors along one wall makes a position solution less stable. The owner then said this was **just curiosity**, not a change of requirements. BinRange continued as a one-anchor home/out zone detector. This exchange is useful context because it rules out telling the story as an unfinished attempt at full location tracking.

The owner also set a physical requirement early: the bin-side hardware had to resemble a small self-powered puck, not an Arduino-sized exposed board. The initial research spec imagined a custom DWM3001C tag with a CR123A cell, then revised toward a CR2450 coin cell and a small moulded enclosure after considering existing UWB pucks. Commercial tags were attractive **only if** their firmware or ranging protocol could be used with a self-built anchor; AirTag-like size did not imply open interoperability. Kinesis and Sunway were explored as candidates, and two Qorvo DWM3001CDK development kits were suggested for a proof of concept before selecting final tag hardware. The actual experiment used Makerfabs WROVER/DW3000 boards, and the deployed bins use KKM K4W tags with removable CR2477 cells.

Two **27 August 2026 orders** make the move from research to hardware concrete. A Makerfabs receipt records **two [ESP32 UWB DW3000 WROVER boards](https://www.makerfabs.com/esp32-uwb-dw3000.html)** for US$91.60 plus US$32.04 shipping, US$123.64 total. Later that day, the [KKM K4W packaged-tag](https://www.alibaba.com/product-detail/Ultra-Wideband-UWB-Tags-for-RTLS_1601366460275.html) supplier said its small enclosed tag had an accelerometer, could run the owner's firmware, and had a programming connection accessible via headers; it offered a matching programming jig. The supplier quoted **ten sample tags at US$25 each, a US$35 jig and US$45 shipping, totalling US$330**. Its order record was marked completed and listed a shipping term of 15 days after initial payment, but it does not establish the actual dispatch or delivery date. The supplier described the enclosure as IP67 and offered a schematic after sample payment; those were supplier statements, not independently verified weather or documentation results. The development boards and packaged tags were therefore sourced in parallel, before the September ranging experiment. These records explain why both kinds of hardware were on hand, though not why Makerfabs was preferred over the originally suggested Qorvo development kits. The prices here are historical order figures, not current quotes.

One shared shopping link needs careful labelling: RobotShop's [“Makerfabs ESP32 UWB Pro”](https://uk.robotshop.com/products/esp32-uwb-pro) describes a **DW1000** board. It is a related product reference, **not** the DW3000 model identified by the Makerfabs receipt and used in BinRange. Likewise, the K4W listing's multi-year battery figure is stated for a BLE advertising interval, not for this project's UWB firmware, so it is not evidence of BinRange battery life.

Some early numbers were **design targets and projections**, not outcomes: a 30-minute heartbeat, a greater-than-two-year battery ambition, rapid movement detection and very few false reminders. The field prototype later used its own settings and still lacks the current measurements and long observation needed for a battery-life claim. The original “no recent packet means Unknown, never Out” rule was also refined by field evidence: silence alone still proves nothing, but a previously observed departure can be remembered as presumed Out.

## How the build unfolded

### 1. Prove the radio link first — 7–8 September

The earliest accessible BinRange working session began with **two Makerfabs ESP32-WROVER/DW3000 boards connected by USB** and the request to see whether they could range over UWB. We added a local web view so the boards could be separated and observed without carrying a cable between them, then measured known distances and tried an outdoor walk.

This stage established both the promise and the limits of the technology. In the recorded two-board tests, an upright orientation improved success at about 10 m from 37% to 100%; a longer, slower radio configuration also worked where the initial short/fast setting did not. A calibrated measurement at a surveyed 10.1 m averaged 10.0912 m with a 0.030 m standard deviation in that setup. The outdoor development-board walk was reliable to roughly 30 m, intermittent beyond that, with the furthest recorded reading at 37.28 m. A car could completely block the path. These are **development-board observations**, not guarantees for a tag mounted under a bin rim.

The software direction changed during the same discussions. We considered an ESPHome component, then dropped it because it added little to the intended system. The anchor instead publishes MQTT and exposes separate per-tag devices and diagnostics to Home Assistant. The existing Waste Collection Schedule integration supplies dates; BinRange supplies movement, range and health. That left the measurement path independent of Home Assistant and avoided an extra BinRange server or cloud service.

At this point the second WROVER board could impersonate different tag identities for integration testing. That helped build the dashboard and MQTT discovery before real tags arrived, but those dummy devices were later cleaned out of the live Home Assistant setup.

### 2. Make it work with real, battery-powered tags — 18–20 September

The actual tags were KKM K4W units with an nRF52833, DW3110 UWB radio and LIS3DH accelerometer. Their arrival changed the work from network experiments to careful hardware bring-up. A spare Nesso device became an SWD programming probe for the clip-on pogo-pin jig. The development tag went first; packaged units were commissioned one at a time, physically labelled, associated with a bin, then returned to their cases with batteries fitted. The distinction between the vendor's printed label, immutable chip identity, chosen UWB ID and Bluetooth address mattered. A printed QR code was not treated as proof of the on-air identity.

Battery life was a design constraint from the beginning, but the discussion moved away from a fast fixed reporting rate. The chosen default behaviour was motion-triggered reporting at about **5 seconds while moving**, settling after quiet, and a **10-minute stationary check-in**, with UWB sleeping between attempts. A separate six-hour absence warning was proposed to catch a missing tag without confusing normal slow check-ins with failure. Voltage, wake counts, motion state and missed exchanges became telemetry. The project explicitly held back from turning a short voltage trace into a battery-life claim. Remote interval controls were later added and verified end to end; the installed fleet was then changed to **30-minute stationary check-ins** while retaining 5-second moving reports. The 10-minute figure remains the firmware default in the general documentation, so a blog post should distinguish default behaviour from the live setting.

The safe-update requirement became a substantial part of the project. First installation needs SWD; routine application updates were designed as signed BLE transfers through the anchor, with the previous application retained for rollback. An update is only reported successful after the tag itself shows the **exact expected image hash and local confirmation**. The tests exercised bad images, interrupted uploads, loss of power at selected stages, watchdog recovery and anchor absence. A persistent anchor identity and existing Bluetooth bonds had to survive updates. The first complete anchor-and-tag OTA journey succeeded, though one bench run still needed a remote retry. Later, the production anchor and all six tags were updated over the air without re-pairing. That proves the route works; it does not prove every future update will be unattended.

Commissioning exposed a specific multi-tag bug: the pinned Bluetooth library sized one kind of stored peer record by simultaneous connections rather than the number of permitted bonds. The first pairing of a further tag could fail even though keys had been stored. A reproducible backend test led to a capacity fix, after which a new physical peer paired without wiping existing bonds. This is a good example of why the leap from **one demo tag** to **six real devices** was more than repetition.

### 3. Let the installation dictate the enclosure — 19–26 September

The WROVER case started as a dimensioned OpenSCAD design. A screw-based version passed an initial fit check, but tiny nuts, bolts and PLA tolerances made it awkward, and the board could rattle because the fixings did not locate it positively. The project owner redirected the design toward a **zero-screw, pure-PLA case**: tapered pins to locate the board, printed flex features to hold it down, and a lid that actually stayed closed.

The iterations were physical feedback, not just CAD revisions. External flexible catches held the board but barely retained the lid. An internal lip improved the fit; deeper hooks improved retention but could still be pulled free. Enlarging those hooks to the wall depth broke both roots during insertion. A torsion-arm variant was drafted, then research into other printed snap-fit enclosures suggested a better change: overlapping base and lid walls with several shallow catches rather than two tall, vulnerable ones. The user-tested v7.0.0 was described as “really good.” v7.1.0 widened the board-locating cone roots and centred the vents; it became the accepted working case. A later v7.2.0 DIN-rail base and clip exists as an **experimental CAD candidate**, not a proven replacement for v7.1.0.

The enclosure history is worth retaining in a blog: the print failures explain the final shape. CAD collision checks could establish that parts should mate; only a print showed whether the catch survived insertion and resisted the board springs. The anchor was subsequently wall mounted in an enclosure, and tags were fitted to all six bins. The repository includes cleaned installation photos and case renders.

### 4. Turn readings into useful Home Assistant behaviour — 20–27 September

The daily dashboard was deliberately separated from diagnostics. The ordinary view should show the next collection, compact bin states and problems needing attention; the technical view retains ranges, reception and anchor data. For this site the initial location rule was **inside 10 m = Home; beyond 10 m = Out**, subject to a fresh reading. It is a local threshold, not a universal one: one anchor measures distance, not direction, so two locations at the same radius cannot be distinguished.

The notification schedule settled on four grouped phases, sent to a deliberately configured phone group:

| Time | Meaning |
| --- | --- |
| 18:00 before collection | Remind about due bins still confidently Home |
| 21:00 before collection | Urgent reminder if they are still Home |
| 06:00 on collection day | Final urgent reminder if they are still Home |
| 18:00 the following day | Bring-in reminder for due bins still Out |

The automation records attempts per phase to avoid duplicate pushes and uses the Waste Collection Schedule calendar for due categories. Unknown or unavailable location is not enough evidence to accuse someone of forgetting a bin. The separate return message originally meant “scheduled bins are still out,” **not** “they were definitely collected.” A public, placeholder-based YAML example and setup guide were committed; the household's entity IDs, phone membership and credentials were kept in ignored local records. The phone screenshots in the README show the desired messages, while the installed automation and field tests determine when they are actually sent.

When the reminder schedule was designed, the owner asked whether collection-day telemetry might eventually identify emptying. A later, early-October retrospective of the 22 September collection showed why that was difficult: General Waste, both Recycling bins and Compost stopped reporting during much of the collection window and reappeared around 17:15–17:17; Garden and Glass continued reporting. Wake counters increased during some gaps, showing activity without locating its moment or cause. Without the owner's observed handling and collection times, the history could not label ordinary handling versus emptying. Meanwhile, the 27 September “just emptied” request became a new cross-device feature. Instead of trying to infer collection from time, range or generic motion alone, the tag uses its existing accelerometer to measure gravity-relative orientation from an upright reference. A sustained tilt **strictly greater than 90°** records a persistent tip event; the anchor carries it to MQTT, and Home Assistant treats a recent tip on a due, confidently Out bin as an **emptying assumption**. Multiple qualifying bins are grouped for 60 seconds. The tag and anchor releases were installed on all six bins, and the Home Assistant automation was enabled. This is a designed heuristic, not proof that a council crew emptied the bin: an owner can tip a bin too, and a tip may reach Home Assistant too late to qualify.

The first implementation checked pending tips every five seconds. The user challenged that as excessive for events that occur only a few times a week. It was replaced with an MQTT-led flow and a timer that runs only while a grouping or recovery deadline is pending. The saved ledger supports duplicate suppression and recovery after a Home Assistant restart. The ordinary scheduled reminders remain a fallback.

Making the project public required its own clean-up. The early development history contained local installation detail, so the public repository was started with a sanitised initial commit on 20 September. Reusable instructions, firmware and selected screenshots were kept; credentials, physical identifiers, household schedules and provisioned images stayed in ignored local storage. Later product photos were resized and stripped of metadata. A subsequent health review found old configuration/reboot endpoints that needed admin protection, a JSON-escaping defect and obsolete development controls; the source fixes were verified locally, while installation of those firmware fixes was reported separately from the review. Public availability should also not be read as a blanket open-source licence: the repository had not selected one at the time of writing.

### 5. A closely examined Garden collection exposed the gaps — 28 September

The Garden bin provided a useful end-to-end field observation. Recorded movement began at **07:05**, distance crossed the 10 m Home/Out threshold at **07:05:14**, and reports then stopped arriving while the bin was away. A single tip was reconstructed at about **09:27** from the event age carried in the later report. Reports resumed at **10:25**, by which time that tip was about **58 minutes old**. The bin crossed back inside the threshold at **10:25:17** and settled near its original storage distance. Normal stationary reports resumed.

Several parts worked: departure and return were visible when fresh reports arrived, the tag retained the tip through the radio gap, and settling resumed. But the tip exceeded the automation's **30-minute acceptance limit**, so the emptying message did not send. Other bins kept reporting, and the anchor showed no MQTT failure during the gap; the exact reason the Garden tag was unreachable at the collection position was not established. This cycle did **not** validate the grouping message or duplicate protection on a real collection.

The put-out reminders also did not send. Their traces showed the scheduled runs executed but found no due calendar events. Investigation found the council source configured twice, once in YAML and once through the integration UI; the empty YAML calendar blocked the working integration calendar. The duplicate was removed, the calendar/update action repaired, and the calendar again displayed upcoming events. This was an integration/configuration failure, not evidence that the position logic alone was enough.

The radio gap also changed the location model. Initially, an Out bin with stale reception became Unknown, which was technically cautious but practically misleading: once the bin had been positively seen leaving, a long absence at the kerb should still read **presumed Out**, with reception health shown separately. Across all six bins, the revised rule retains an observed Out departure through lost contact and Home Assistant restarts; only a **fresh inside-threshold reading** returns it Home. Home followed by silence remains Unknown because no departure was observed. Return reminders can use this presumed-Out state; put-out reminders still require a fresh Home reading. This live change is reflected in current local docs and examples, some of which are still uncommitted as of this note.

## Decisions that changed along the way

| Early idea or problem | What the project settled on | Why it changed |
| --- | --- | --- |
| Two WROVER boards as peers | One fixed anchor and six battery tags | The boards established the link; packaged tags answered the real household question. |
| Cheap BLE proximity tags and an outdoor proxy | UWB time-of-flight ranging | The original system consumed batteries, jittered and was unreliable in this installation. |
| Fixed berth magnet or Hall sensor | Range-based home zone | The bins have no consistent docking spots. |
| Full 2D/3D positioning | One-anchor Home/Out classification | The multi-anchor geometry question was curiosity, not a requirement. |
| CR123A/CR2450 custom puck and Qorvo dev-kit shortlist | KKM K4W CR2477 tags and Makerfabs WROVER anchor | Separate 27 August orders put two development boards and ten programmable packaged tag samples on the way at the same time; the reason for preferring Makerfabs over the suggested Qorvo kits is not documented. |
| ESPHome component | Direct MQTT discovery into Home Assistant | A separate component added little to this architecture. |
| Frequent fixed polling | Accelerometer-triggered fast reports, slow idle check-ins | Motion matters more than constant stationary ranging; battery cost remains to be measured. |
| Ranging alone could imply location | Site-specific Home/Out threshold plus independent freshness | UWB distance is neither a coordinate nor proof of continued reception. |
| Stale Out becomes Unknown | Persist an observed Out departure, with separate radio health | The closely examined Garden cycle showed prolonged loss of coverage at the kerb. |
| Movement or elapsed time might mean “collected” | Calibrated >90° tip event, due-date and Out checks | Ordinary handling and silence were too ambiguous. |
| Poll tipping automation every five seconds | MQTT events plus a deadline timer | The event rate did not justify continuous automation runs. |
| Small screws and tall snap hooks for the case | Locating cones, board springs and overlapping shallow catches | Physical prints exposed rattling, poor retention and broken hook roots. |
| USB/jig as maintenance path | Signed BLE updates through the anchor, with SWD rescue | The installed bins needed maintainability without repeated disassembly. |

## What is established, and what still needs evidence

**Established:** six tags have been commissioned and mounted, a fixed anchor is installed, tag-initiated ranging reaches MQTT/Home Assistant, the calendar-backed reminder automation and tipping automation exist, remote check-in controls work, and signed anchor/tag OTA was demonstrated on the installed fleet. The 28 September Garden collection produced a real departure, stored tip and return trace. The case v7.1.0 is the accepted printable design.

**Still to establish:** reliable coverage at every bin's storage and collection positions; several full collection cycles in which reminders and tip notifications are actually delivered; representative whole-tag current and multi-week battery behaviour; weather exposure and mounting longevity; and repeatable unattended update connections. The live 30-minute idle setting means a stationary bin may be silent by design, so monitoring needs to distinguish a planned interval from an outage. The first Garden tip was detected **but did not cause an emptying notification**. The DIN-rail clip has not been physically accepted.

## A possible blog arc

1. **Open with the older frustration:** BLE tags drained batteries and gave jittery “nearby” hints while the calendar still could not know whether a bin moved.
2. **The choice of UWB:** reject fixed dock sensors because bins never park precisely, ask for a small battery puck, and choose a single home-zone range rather than full positioning.
3. **The first bench experiment:** two development boards, a tape-measured gap, surprising antenna orientation effects and a car blocking radio.
4. **From demo to fleet:** six identified tags, a battery budget, safe commissioning and the unexpectedly difficult update path.
5. **The case that fought back:** rattling boards, weak catches, broken PLA hooks and the accepted overlapping-shell design.
6. **Making the data useful:** the six-bin dashboard and notifications tied to the household's collection schedule.
7. **Reality at the kerb:** the 28 September Garden cycle detected the tip but missed the message; an empty calendar independently stopped reminders.
8. **Where it stands:** a working field prototype that now has honest handling of stale data, with coverage, battery life and unattended updates left to prove.

Useful figures already in the repository: the [walk-test graph](images/uwb-walk-test.png), [installed anchor photo](images/wall-mounted-anchor-enclosure.png), [tag mounting photos](../README.md#the-hardware), [v7.1.0 case renders](../hardware/wrover-case/README.md), and [phone screenshots](../README.md#phone-reminders). The 28 September Garden-cycle trace is in ignored local deployment evidence and would need deliberate sanitisation before publication.

## First-person moments worth keeping

- The origin: “I had an idea a number of years ago to stick cheap BLE tags on my wheelie bins...” The original system's battery, jitter and proxy problems make a stronger opening than an abstract explanation of UWB.
- The physical constraint: “passive magnet etc is out, the 'docked' location is neither consistent nor accurate” and “i can't be sticking something that resembles an arduino on there, it's too large.” Those two corrections explain both the radio decision and the small packaged tags.
- The scope correction: “nah i was just curious.” This followed the discussion of four-anchor positioning and confirms that BinRange was never meant to map each bin in 2D or 3D.
- The print feedback: the v4 board pegs and springs worked, but the lid “can move around all over the place”; later, the deep catch roots snapped during insertion. This is the human testing that led to the accepted case.
- The installation milestone: “I THINK this is all good and working now!” was said when the anchor was wall mounted and every bin tagged. The subsequent collection-day investigation provides the honest next scene.
- The automation correction: “This feels excessive, no?” was the response to a five-second polling trigger and led to the event-driven timer.

## Source trail and gaps

- **Conversation history used:** the owner-pasted early BLE-to-UWB research discussion, the separate anchor-geometry curiosity exchange, the 27 August supplier/order exchange, the Makerfabs receipt and the supplied product links; the long “BinRange Software” session beginning 7 September; “Design WROVER board case”; “Add Home Assistant idle check-in controls”; “Check Home Assistant automation”; the late-September case/photo, notification, tipping, calendar-repair and Garden-cycle tasks. These supplied the requests, corrections and reported live outcomes above.
- **Task IDs for retrieval in Codex:** `01a081f5-38f7-7ff3-b08b-e04a57e24f5c` (main build), `01a0b945-d3f3-7af2-aa0f-ddb6dfa5a854` (case), `01a0bec6-8adc-7381-b79a-03911e19a44d` (intervals/OTA), `01a0c023-3e71-7301-a77e-8d9693ed978a` (reminders and 22 September review), `01a0e390-0970-7293-907d-9391007845aa` (tipping), `01a0e786-8711-7b50-88f3-cc03a26e63e7` (calendar repair), and `01a0e788-745c-7fe3-8a57-6e6ed1f60f68` (Garden cycle and remembered Out).
- **Repository cross-checks:** [README](../README.md), [findings](findings.md), [roadmap](current-work.md), [hardware reference](hardware.md), [MQTT and location model](mqtt.md), [tag-update contract](tag-updates.md), [reminder and tipping guide](../examples/home-assistant/README.md), and [case history](../hardware/wrover-case/README.md). The first public Git history starts on 20 September, after the initial experiments.
- **Early-history limit:** the pasted conversations supply the original BLE problem, rejected fixed-berth alternative, puck requirement, hardware shortlist, geometry side question and the later tag order. They do not establish the exact date of the years-old first idea or every reason the final hardware differed from the shortlist. Some other conversations from the older “UWB Bin Tags” project may still be absent; this account does not invent their contents.
- **Privacy:** this file intentionally omits credentials, addresses, physical serials, phone identifiers, exact home layout and private deployment records. Review any local telemetry/screenshots before using them in a public post.

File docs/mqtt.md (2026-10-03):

# MQTT and Home Assistant

One powered anchor runs custom firmware and publishes tag measurements to an
existing MQTT broker. Each adopted tag has its own Home Assistant device;
the anchor has a diagnostics device. No ESPHome component is required.

## Ranging and topic contract

Tags initiate DS-TWR: POLL → anchor RESPONSE → tag FINAL. The anchor calculates
distance from timestamps. Radio work owns SPI on core 1; the main loop owns
registry/MQTT on core 0 alongside the BLE worker. Hardware coexistence matters.
Ranging must not depend on Wi-Fi, broker or HA availability.

| Topic | Purpose |
| --- | --- |
| `binrange/anchor/<anchor>/status` | Retained availability / last will |
| `binrange/anchor/<anchor>/state` | Radio/network/system diagnostics |
| `binrange/anchor/<anchor>/cmd/<command>` | Non-retained radio/diagnostic controls; current radio settings are in anchor state |
| `binrange/tag/<tag>/config` | Retained adoption/name/settings |
| `binrange/tag/<tag>/anchor/<anchor>/state` | Distance, signal quality, telemetry |
| `binrange/tag/<tag>/anchor/<anchor>/update` | Status-only tag updater diagnostics |
| `binrange/anchor/<anchor>/update` | Status-only anchor updater diagnostics |

Tag IDs are four lowercase hexadecimal digits. Preserve topic/discovery IDs and
calibration when changing labels. HA discovery prefix is `homeassistant`;
device identifiers are `binrange_tag_<tag>` and `binrange_anchor_<anchor>`.

Unknown tags generate sightings, not automatic HA devices. Retained adoption
accepts name, area, offset and stale_after; source authority is `publisher.cpp`
and `core/registry.*`. Empty adoption removes registry/discovery, not necessarily
every retained topic/history row. Cleanup must target exact IDs, not all HA data.

## Measurement and freshness

- `ts` is real reception time reconstructed from the radio event and valid wall
  clock. Stale/reconnect publication must not advance it. Without reception or
  valid clock it is null. `age` is age at publication, not a ticking value.
- After anchor restart, measurements remain unknown until fresh reception.
  Previous absence age is not reconstructed; anchor availability is separate.
- `stale` is short-term range freshness: last-known moving tags become stale
  after 20 s; otherwise the configured per-tag timeout applies.
- `missing` is the independent long absence threshold, initially six hours.
  Never-heard adoption starts unknown, then alarms at timeout. Replaying
  retained configuration does not postpone it; raised absence clears only
  after a real reception.

Extended FINAL is 41 bytes: timestamps 10–21, millivolts 22–23, flags 24
(moving bit 0 / sensor-fault bit 1 / tip-ready bit 2), missed exchanges 25–26,
wakes 27–30, persistent tip count 31–34, tip age in seconds 35–38, FCS 39–40.
Integers are little-endian; legacy 24/26/29/33-byte layouts remain accepted.
Misses/wakes saturate and reset on boot. Wakes count motion episodes, not IRQs.

Unknown telemetry is null, not zero/stationary. Zero millivolts clears an old
voltage; sensor fault makes motion unknown. `ok` is unknown because received
FINALs cannot establish an end-to-end success denominator. MQTT binary templates
use native None for unknown, not OFF.

Tipping telemetry is repeated in every normal state report:

- `tip_count` is a persistent counter of confirmed tipping events. It identifies
  an event across missing radio reports and restarts; it is not a collection count.
- `tip_age_s` is elapsed time since the most recent confirmed tip, measured at
  the tag's report. The wire sentinel `UINT32_MAX` becomes JSON null when no tip
  occurred in this boot, even if a persistent count exists. Stale/reconnect
  publication preserves both this age and the original reception `ts`.
- `tip_ready` is true only when the tag has a calibrated, healthy detector.
  A sensor fault forces false. Older firmware makes all three fields null and
  clears previously received tipping telemetry.

Home Assistant discovers diagnostic Tip count, Tip age (seconds), and Tip ready
entities, using `tip_count`, `tip_age_s`, and `tip_ready` discovery keys. Tip count
has no `total_increasing` state class. Consumers can estimate the event time as
`ts - tip_age_s`, but must reject unknown/stale timestamps and deduplicate the
persistent counter before producing notifications.

## Home Assistant presentation

Build dashboards from the installation's actual discovered entities. A useful
split is a compact daily page (bin status, next collection, problems, battery)
and a monitoring page (range age, voltage, wakes, signal, anchor and OTA health).
Keep deployment-specific card layouts/entity mappings outside the public source.

A simple initial location rule is a chosen distance threshold:
fresh distance inside it is Home, outside is Out, otherwise Unknown.
For bins that leave radio coverage, retain an observed Out state until a fresh
inside-threshold reading confirms Home. Store that departure in a restored HA
helper with no configured initial value; silence must not clear it, including
across HA restarts. Home followed by silence still becomes Unknown. Keep range
freshness and missing-check-in diagnostics unchanged so presumed Out does not
claim a live radio connection.
The threshold must suit the installed storage/collection geometry; one anchor
cannot distinguish equal-radius locations. Hysteresis/settling should be explicit
if added. Row timestamps are HA updates, not necessarily physical motion times.

Firmware publishes voltage in V with measurement state class. Optional percentage
helpers should be labelled estimates, reject invalid/out-of-range values and
unavailable check-in health, and retain the measured voltage for diagnosis.
The experimental UI used generic
[Zigbee2MQTT `3V_2100`](https://github.com/Koenkk/zigbee-herdsman-converters/blob/master/src/lib/utils.ts)
interpolation; this is not a CR2477-specific capacity/runtime model.
No universal battery alarm threshold is established.

Voltage measurements can have long-term statistics; wake counts, reception
timestamps and binary health histories need separate retention planning.
Averaged missed-counter values are not an event total. Handle counter resets
and distinguish observer/network gaps from tag silence.

## Collection scheduling and automations

Collection dates come from the brilliant
[Waste Collection Schedule](https://github.com/mampfes/hacs_waste_collection_schedule)
Home Assistant integration, installed through HACS. Configure the appropriate
local provider or calendar there; BinRange does not duplicate its schedule logic.

Map provider categories to your named tags. A category may cover more than one
bin. Keep provider entity IDs, mappings, notification targets and household times
in local HA configuration.

The [collection reminder example](../examples/home-assistant/README.md) includes
placeholder YAML combining due collections with confident Home/Out state. It
groups reminders, prevents duplicate phase attempts, handles changed schedules
and supports put-out plus return reminders. Configure its entity IDs, provider
categories, persistent Text helpers and phone notification group before enabling.
Put-out reminders require fresh Home. Return reminders may use a remembered Out
departure while reception is stale; Unknown/unavailable locations are excluded.
Elapsed time alone proves neither departure, collection nor return. Deliberately replace overlapping
old automations rather than installing duplicates.

## Controls and security

Broker settings are runtime-configurable/persistent in the anchor UI. Never
return/log passwords. Show connection state, failures and recent publications;
a publish attempt does not prove HA received it.

Normal HA controls cover radio/diagnostics. Pairing, signed upload and tag updates
require separate admin authorization in the anchor UI. Updater MQTT entities are
status-only; broker credentials do not grant admin authority.

The anchor's web settings, broker changes, counter reset and reboot also require
the admin password. The page authenticates before each action and sends the
per-boot CSRF token with its POST. Failed actions are shown and are not retried
automatically. Read-only diagnostics remain available without signing in.

Use trusted-LAN HTTP/MQTT, not direct Internet exposure. Broker reconnects publish
coherent last state with its true age.

## Changing tag check-in intervals

After installing an anchor build with motion-setting controls, open the tag's
Home Assistant device page under **Settings → Devices & services → MQTT**. Its
Configuration section includes:

- **Stationary check-in interval:** 60–3,600 seconds (default 600).
- **Moving check-in interval:** 1–60 seconds (default 5).
- **Read check-in intervals:** refreshes the values from the tag.

The two number controls accept whole seconds. They require the tag to be adopted
and paired with this anchor, running confirmed tag firmware **0.2.6 or later** (configuration schema 1).
The matching anchor firmware is **0.2.4 or later**. Pairing remains an explicit operation in the anchor UI.
The anchor must be within Bluetooth range; UWB range alone is not sufficient.
No Home Assistant YAML or additional service is required. MQTT discovery creates
these controls on the existing tag device. Unpaired controls are unavailable.

A change queues behind current firmware maintenance. The anchor connects using
its existing authenticated bond, verifies the tag's hardware identity, reads all
five motion settings, changes only the requested interval, saves the complete
record, reads it back, and checks that application finished without a sensor
error. Sensitivity, motion duration, settling time and the other interval are
preserved. Changes survive tag restarts; reflashing is unnecessary.

**Check-in settings status** and **Check-in settings error** expose queue,
read/write, verification and failure state. The number values come from confirmed
tag settings, not an optimistic echo of the requested value. An uncertain write
makes them unknown. If a tag is unreachable or a request fails, bring it into
Bluetooth range and use **Read check-in intervals** before resubmitting a change.
Failed writes are not automatically replayed. Pending commands are volatile:
after an anchor restart it reads the tag again instead of replaying commands.
Initial reads happen for paired adopted tags, with read-only refreshes every
15 minutes, including after failed reads. These retries only read settings;
they never replay a failed write. The refresh button requests an earlier read.

| Topic | Payload |
| --- | --- |
| `binrange/tag/<tag>/anchor/a/motion/idle/set` | Stationary interval in whole seconds |
| `binrange/tag/<tag>/anchor/a/motion/moving/set` | Moving interval in whole seconds |
| `binrange/tag/<tag>/anchor/a/motion/refresh/set` | `PRESS` |
| `binrange/tag/<tag>/anchor/a/motion` | Retained JSON: availability, confirmed `idle_ms` / `moving_ms` (or null), status, pending, error and observation age |

Commands must be non-retained. The discovery payloads set `retain: false` and
`optimistic: false`, following the [MQTT Number contract](https://www.home-assistant.io/integrations/number.mqtt/).
The broker's normal authentication and ACLs govern who can change intervals;
limit publishing on these command topics to authorized Home Assistant clients.
Removing adoption cancels queued settings work and removes retained settings
state and discovery. It does not erase the tag's saved settings or Bluetooth bond.

The anchor always responds to tag-initiated exchanges; it has no reporting
interval of its own. The adoption record's `stale_after` is a liveness threshold,
separate from the tag's reporting intervals. Longer intervals reduce reporting
frequency; battery-life effects still need whole-device measurements.

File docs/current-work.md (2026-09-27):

# Roadmap and acceptance

The architecture is settled: motion-triggered battery tags, one powered UWB
anchor, MQTT, per-tag Home Assistant devices, signed BLE maintenance and SWD
rescue. The prototype is in use as a six-tag field installation: the anchor is
wall mounted in its enclosure, tags are fitted to all bins, and the owner reports
the Home Assistant side is looking good.

This is the general project roadmap. Household-specific priorities, identifiers,
addresses, reminder choices and dated observations are deliberately kept outside
Git. For an existing local installation, consult its ignored deployment notes.

## Established

- Real tag-initiated ranging and per-tag MQTT/HA attribution.
- Motion/wake reporting, settling, UWB sleep and ten-minute stationary check-ins.
- Signed BLE application updates, local confirmation and watchdog rollback.
- Persistent anchor identity and bond-preserving recovery.
- Multiple real tags commissioned; per-peer Bluetooth store-capacity defect fixed.
- Separate daily/diagnostic dashboards; freshness distinct from long absence.
- Anchor enclosure wall mounted and all six bins tagged (owner-reported).

Evidence and qualifications are in [findings](findings.md), not an exhaustive
chronological build log.

## Tipping notification implementation

Tag firmware 0.2.7 and anchor 0.2.5 add calibrated gravity-relative tipping events.
The [HA tipping example](../examples/home-assistant/README.md#tipping-triggered-emptying-messages)
assumes a tip beyond 90 degrees means emptying, groups notifications and keeps
scheduled reminders as fallback. Software tests and signed-image checks do not
replace a real installed tipping test. Deployment state and exact artifacts live
in the ignored installation release records.

## Next acceptance work

| Area | Completion criterion |
| --- | --- |
| Installed hardware | Mounting is complete; observe power stability, weather exposure, orientation and battery access in normal use |
| Coverage / location | Each tag checked at storage and collection, while moving and after settling; distances independently measured; threshold has useful margin |
| Battery / motion | Meter-checked voltage, representative whole-tag idle/active current, persisted tuning and no excessive nuisance wakes |
| Reliability | Real fleet activity, missed reports, sensor faults and anchor/broker outages have truthful status and bounded recovery |
| Maintenance | Repeatable bonded slow-advertising OTA without jig assistance or operator retries, exact active hash/local confirmation, representative post-trial interruptions and safe uncertain outcomes |
| HA reminders | Setup is in use; confirm scheduled put-out/return behavior and stale-data handling over real collection cycles |
| Handover | Reproducible signed release, recovery/key backup, current instructions and sanitized evidence |

## Proposed four-week field trial

Observe normal use across several collection cycles without changing firmware
or reporting cadence unnecessarily. It is a reliability/drain screen, not a
capacity test or a battery-lifetime claim.

Record raw voltage trends, real reception gaps, motion/wake-count changes,
local missed-exchange changes, sensor faults, anchor availability/restarts and
broker health. Mark battery swaps, handling, placement and firmware/settings
changes. Counter resets must not be mistaken for negative activity.

HA voltage measurement sensors support hourly long-term statistics. Wake counts,
last-seen and binary health history need explicit retention/export planning.
Check the installation's Recorder retention/exclusions before starting; the
[default detailed-history retention](https://www.home-assistant.io/integrations/recorder/)
is ten days. Do not increase whole-house retention blindly.

Suggested cadence: daily health/data capture, weekly summary and a final
four-week review. Missing observer/anchor access is monitoring unavailable, not
a dead tag. A quiet voltage trace alone cannot establish months of battery life.
The trial is a design recommendation, not an automation installed by this repo.

## Keep the work bounded

Reuse valid physical evidence. Do not repeatedly commission deployed tags or
run bulk OTA transfers merely to poll their batteries. Keep loss/recovery
experiments on a selected development unit; strong checks belong around identity,
authentication, unsafe writes, invalid images, interruptions and false success.

Do not introduce an ESPHome migration, cloud dependency, extra service or
multi-anchor redesign as part of this acceptance phase.

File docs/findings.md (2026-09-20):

# Findings and limitations

Reusable engineering observations from prototype testing. Site addresses,
physical device identifiers, individual bin reports and private release assets
are intentionally excluded. These results are not guarantees for another site.

## UWB link

Tests used two Makerfabs WROVER/DW3000 boards unless noted otherwise.

| Observation | Result / limit |
| --- | --- |
| Antenna orientation matters | At about 10 m, flat→upright improved observed success 37%→100%, with ~13 dB first-path improvement |
| Long PHY helped the weak link | 6.8 Mbps/128-symbol preamble: 1/346 exchanges; 850 kbps/1024: 337/337 in the same indoor setup |
| Calibration is setup-specific | Upright Long at a measured 10.1 m: mean 10.0912 m, standard deviation 0.030 m |
| Outdoor walking test | Reliable to roughly 30 m, intermittent 33–37 m; furthest recorded 37.28 m, with gaps |
| Obstructions | A car could fully block reception; body shadow weakened the signal |
| Very short distances | At roughly 10 cm, readings became multimodal; use distances around 1 m or more for calibration |

Outdoor walk-test distance and signal traces

This graph uses a development/emulator identity, not a packaged tag mounted on
a bin. Absolute RSSI/first-path values lack DW3000 DGC correction and should be
treated as relative indicators. Neither their difference nor range spread is
a validated obstruction classifier. A held flat range is not proof of stillness.

The anchor cannot count POLLs it never receives and cannot derive end-to-end
success rate from received FINALs. Local tag misses are useful but different.

## Motion and power

The 0.2.5 motion baseline demonstrated:

- Actual accelerometer-triggered movement, five-second reports and wake-episode
  increment, followed by a received stationary/settled report.
- A ten-minute idle interval verified independently in MQTT and HA.
- Healthy locally confirmed firmware, watchdog progress and UWB asleep on
  non-halting inspection.
- Motion/settling on a packaged tag as well as the development unit.

This does not establish whole-board current, meter accuracy, all-site nuisance
wake behavior, deliberate-loss recovery or battery lifetime. The radio-sleep
flag is not a current measurement. VDD is sampled after UWB wake, not as a
rested voltage or captured minimum pulse sag. A generic coin-cell percentage
curve is provisional, not a calibrated fuel gauge.

Use unique MQTT observer client IDs and detect observer disconnects; a recorder
losing its own connection can otherwise be mistaken for tag silence.

An isolated 0.2.6 development-tag test changed intervals through Home Assistant,
MQTT and the bonded anchor: observed report spacing was about 60.03 s stationary
and 2.02 s moving. The saved settings survived a tag restart. Original tuning was
restored and read back; temporary HA entities and the test dashboard were removed
with existing dashboard configurations unchanged.

## Integration and recovery

MQTT checks established runtime adoption, per-tag attribution, unknown sightings
without automatic devices, retained settings, last-will availability and
reconnection. During a simulated 45 s broker outage, ranging continued and
state returned after reconnect. The household broker itself was not stopped.
An identity-switching emulator does not prove six-radio fairness.

Signed tag update/recovery checks included:

| Check | Established result |
| --- | --- |
| Upload interruption | Old app remained usable and receiver offsets governed resumption |
| Wrong-key/corrupt image | Known-good confirmed application remained available |
| Pre-main hang / failed radio initialization | Watchdog rollback without a debugger reset |
| Power loss during upload | Recovery to known-good firmware; upload restarted at the receiver's actual offset |
| Power loss during swap | Interrupted installation resumed; not a cut during a flash pulse |
| Anchor absent | Healthy tag could confirm locally without an RF response |
| Remote confirmation request | Rejected; only local health confirmation accepted |
| Anchor restart before trial | Same target/release returned NeedsRelease and resumed after matching restaging |
| Anchor-driven updates | Exact active image hash and local confirmation matched MQTT/HA without re-pairing |

An isolated WROVER/development-tag journey also exercised the anchor's legacy
and authenticated HTTP OTA routes. Its BLE identity and tag association survived
the authenticated update. After one-time test commissioning, the debug connection
was closed and the local window/cooldown expired before an anchor-driven signed
0.2.5-to-0.2.6 update. The anchor eventually verified the exact active hash and
local confirmation without further jig assistance.

That run's first upload request received no reply within the normal 10 s budget.
Bounded recovery completed the transfer on its third connection; a remote operator
retry was then needed for post-reboot verification because the connection budget
was exhausted. A separate 30 s request-budget experiment completed automatically
with two connection attempts, including verification after reboot. Its first
acknowledgement took less than 6 s, so it did not establish the
original timeout's cause or justify changing production deadlines. Test builds
used isolated radio/MQTT identifiers and a third bond slot to preserve the two
original test-tag associations. This proves the wireless upgrade path, not
repeatable unattended reliability. Retain a tested SWD/laptop recovery path.

A subsequent six-tag installed rollout upgraded the production anchor to 0.2.4
and all six tags to signed 0.2.6 entirely OTA using their existing bonds. Every
tag’s exact active image and local confirmation were verified, healthy range
reports resumed, and HA read back the existing 600 s stationary / 5 s moving
settings. Firmware jobs completed within their bounded connection budgets.
Several separate settings reads required remote retries, including one after a
longer quiet interval. The anchor identity and associations survived its single
restart; no production jig access or re-pairing was needed. This is one successful
installed rollout, not proof of unattended connection reliability.

## Resolved multi-peer pairing defect

Pinned NimBLE-Arduino 2.5.1 allocated client-supported-feature records by
simultaneous connections rather than allowed bonds. With one connection and
multiple peers, first pairing could fail after keys were already stored.

Anchor 0.2.3 sizes `MYNEWT_VAL_BLE_STORE_MAX_CSFCS` to
`CONFIG_BT_NIMBLE_MAX_BONDS`. A real-backend regression reproduced the old
capacity failure; a genuinely new physical peer paired on the corrected anchor
without a restart or bond eviction. This does not explain every connection miss.

## Remaining maintenance limits

- Slow connectable advertising can be seen but connections are not yet accepted
  as dependable. Keep bounded attempts/cooldown and existing bonds.
- Cold offset-zero requests intermittently timed out even when the tag accepted
  its first block. Pinned MCUmgr synchronously erases the incoming slot with
  progressive erase disabled. This is a latency stage, not a proven root cause;
  correlate sender/receiver timings before changing deadlines.
- Pinned WebServer holds one global Digest challenge; competing admin clients
  can invalidate each other's login. Cache the helper challenge and avoid
  competing polling. Never replay mutation POSTs after uncertain responses.
- Maintained-tag ranging pauses during bulk transfer. Background UWB/MQTT
  continued during bench tests and one sequential six-tag installed rollout;
  sustained fleet coexistence remains a field gate.

The public [roadmap](current-work.md) lists acceptance; the
[update contract](tag-updates.md) owns safety invariants.

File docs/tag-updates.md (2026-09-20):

# Tag-update contract and integration constraints

Use this for updater implementation; [current work](current-work.md) alone owns
status and acceptance tasks. Existing physical checks are in [findings](findings.md).

## Ownership and success

The anchor runs ranging, registry/MQTT, local web admin and one serialized BLE
updater. Main loop owns jobs, their NVS snapshot and publication; worker owns
BLE and its identity/bond persistence; radio owns SPI on core 1. Bounded
commands/events carry nonreused session/operation IDs.
Discard stale events; keep callback contexts and staged bytes alive until actual
transport quiescence. Disconnect timeout or queue overflow fails visibly closed.

An update succeeds only when the commissioned hardware reports the expected
active image hash **and local confirmation**. Accepted bytes, bootable metadata,
version text or reset acknowledgment are insufficient. `0.2.2` versus `0.2.2+0`
is not a hash mismatch. The anchor never sends remote confirmation.

## Tag recovery and access

- MCUboot signed dual-slot offset swap retains the previous app. Only inactive
  application space is written by OTA; preserve identity/versioned settings and
  their compatibility with the previous image. Bootloader/UICR updates, mass
  erase/readout lock and rollback-resistant counters are outside this stage.
- MCUboot verifies the project signature. Keep the private key off anchor and
  Git, backed up securely; no demonstration key. Anchor metadata parsing is not
  cryptographic signature verification.
- Trial confirmation needs radio initialization, BLE management and continuing
  main-loop progress during bounded local observation. Anchor RF reception is
  not required. Early watchdog protection must recover pre-main hangs and allow
  interrupted swaps to resume; the SDK watchdog-feed macro alone starts no timer.
- Management needs an explicit bounded commissioning/maintenance window and
  authenticated authorization for every exposed command. Enable only required
  groups, not sample shell/filesystem/erase capabilities. Physical KEY wiring
  must be verified before relying on it. Keep an authorized laptop/SWD rescue path.
- Associate adopted UWB ID, selected public/static BLE address and immutable
  hardware identity after PIN-authenticated commissioning. A name/address alone
  is not identity. Lost bonds require operator action, not automatic re-pairing.
- Expose version, image hash, confirmation, reset reason and maintenance health.
  Preserve ranging outside bounded maintenance sessions.
- Queue for rendezvous rather than promising instant reachability. Current tag
  policy is 5 s moving / 10 min idle UWB reports, sleeping UWB between attempts.
  BLE remains discoverable with slow 2.0–2.1 s connectable advertising and a short
  fast-advertising local maintenance window. This default tradeoff still
  needs whole-board current measurements; no battery-life claim follows from it.
  Advertising restart waits for connection recycling; the callback only signals
  the main owner, which performs HCI work.

Exact partition layout, signing, installation preflight and recovery are owned by
the [signed build guide](../firmware/k4w-tag/BUILD.md).

## Anchor storage and state

- One immutable staged image in 212992-byte PSRAM capacity. No internal-heap
  fallback, formatting or partition change; preserve both 1280-KiB anchor OTA slots.
- Check NVS read/write/commit results. Missing and unreadable are different;
  unreadable credentials/jobs must not become defaults. Persist phase, exact
  target/release and attempt checkpoints before upload, trial and reset, not
  per packet. Persistence uncertainty disables unsafe operations.
- Keep the anchor's static-random BLE identity in checked, board-bound NVS
  (`binble/identity`), independent of jobs. Reapply it before scanning/connecting.
  Never replace an existing identity or bond on boot. Missing identity with saved
  bonds/associations requires explicit recovery; unreadable identity disables BLE.
  For legacy recovery only, build with `BINRANGE_BLE_IDENTITY_FILE` pointing to a
  private mode-0600 JSON containing `anchor_mac` (Wi-Fi MAC) and `ble_address`
  (the verified static-random address), both colon-separated display order.
  Generated bootstrap input is Git-ignored and board-specific, not a generic
  firmware default. After durable recovery, ordinary builds omit this input.
  `/api/tag-updates.local_ble_address` reports the initialized identity, or null.
- Use the explicit CRC/versioned snapshot codec, uniqueness and no-live-job-
  eviction rules. On restart preserve job IDs/targets/hashes; discard volatile
  offsets and monotonic timestamps. Lost staging means NeedsRelease, never
  silently another image/tag. Free-entry count is only a capacity estimate.
- Every session checks identity and slots. Initial upload sends off=0, length
  and whole-file SHA; receiver offsets govern continuation. Inspect a matching
  unconfirmed active image instead of overwriting it. Pending trial on an old
  image needs explicit action; uncertainty after trial/reset means inspect,
  not replay or claim cancellation. Keep maintenance state bounded and visible.
- Use long-lived snapshot scratch, not large ESP32 stack locals. Existing
  measured storage begin stack was 288 bytes; decoder 3984 bytes.

## Pinned BLE integration

Target is espressif32 6.5.0 / Arduino-ESP32 2.0.14 / NimBLE-Arduino 2.5.1.
Read the actual pinned headers rather than those of another installed SDK.
Keep ARDUINO_RUNNING_CORE=0 and CONFIG_BT_NIMBLE_PINNED_TO_CORE=0 explicit in
build flags. Measure final linked fit and live coexistence before deployment.
Use Wi-Fi `WIFI_PS_MIN_MODEM`, not the old `setSleep(false)` setting: the pinned
ESP-IDF coexistence layer aborts when BLE starts with `WIFI_PS_NONE`.
The BLE worker checks this precondition before initialization.

- Use raw asynchronous GAP/GATT with bounded callbacks and application deadlines;
  C++ discovery/read/write helpers can block. Avoid implicit retries/security.
- Preserve full-source-hash checks in scripts/anchor_ble_build.py. Both the C++
  client and native ble_sm.c key-missing (518) path can silently retry pairing;
  both must fail closed. Native security_initiate can also pair when no key is found: ordinary
  updates must use a validated existing bond, not enter commissioning implicitly.
- Ignore unsolicited peripheral Security Requests; the worker alone starts
  authorized security. Check bond restoration at startup, latch store failures,
  and reject replacement of existing key material. RAM-only keys are not proof
  of persistence; a store fault disables maintenance until restart.
- Reject store-full rather than evict bonds. Reject default numeric/passkey
  acceptance. Use the supplied PIN only for explicit commissioning; clear
  temporary PIN/key material and never log it.
- Verify encryption, MITM/authentication, bonding, 16-byte key and matching stored
  ble_store_value_sec.sc. NimBLEConnInfo alone cannot establish Secure Connections.
- Associations store addresses MSB-first; native ble_addr_t is LSB-first. Check
  exact peer identity/OTA address, connection, value handle and operation.
- Scan 15 s; connect 15 s; outer connect operation deadline 35 s (scan, connect,
  queue/callback margin); request 10 s; idle 45 s; session at most 540 s.
  At most three attempts with at least 60 s cooldown after exhaustion/expiry;
  confirmation observation at most 150 s. Fragment writes at negotiated MTU-3.
- Reuse bounded SMP/image codecs and actual-tag CBOR fixtures, including
  indefinite maps/arrays. Do not add an alternate parser or confirm command.

## Web administration and feedback

Private bootstrap password: local-backups/anchor-admin-password.txt (0600).
BINRANGE_ADMIN_FILE passes a path, never secret text; relative paths resolve
from firmware/anchor. Omitted input clears stale generated bootstrap; explicit
invalid input fails the build. Valid stored credentials take precedence.
Generated headers/provisioned binaries remain private.

Digest must match actual URI and qop=auth; mutations also require per-boot CSRF.
Protect every multipart callback/finalization, including parser error exits.
Pinned WebServer handles the request synchronously inside handleClient(); keep
cleanup around that scope and finalize once. Recheck if upgrading the SDK.
The hash-pinned project-local WebServer parser replacement bounds headers,
text fields, disconnect handling and the total multipart deadline before
callbacks run; do not modify the shared installed framework.
Persist password changes before activation; rotation requires an explicit restart.
ArduinoOTA uses the same admin secret with mDNS disabled to preserve HTTP discovery.
This is trusted-LAN HTTP, not TLS or Internet-safe access.

Bound inputs, render strings as text, clear secret fields, never serialize secrets.
Use 400 for invalid input, 409 for conflicts, 507 for capacity. No automatic POST
retries. Poll once per second with one request in flight; retain last-known values
and forms but label stale/disconnected state honestly. Page/API schema lives in
firmware/anchor/src/update_page.h, not a second document.

Publish retained per-tag phase, bytes, error, expected/observed version/hash,
timestamps and restart/maintenance state under the [MQTT contract](mqtt.md).
Updater MQTT is status-only; broker credentials cannot bypass admin authorization.

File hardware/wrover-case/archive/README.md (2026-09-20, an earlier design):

# Original prototype archive

`pre-versioning-originals.zip` preserves every previous case source, export, historical README, check and distribution ZIP at its original relative path. `pre-versioning-sha256.json` records every archived file hash; all entries were verified before reorganising. These are historical records, not current printing instructions.

The unversioned `exports/case.3mf` and `exports/base.png` were not assigned a version because their provenance was not verified. No standalone v1 model was found. Duplicate aliases and small test coupons remain only in this archive. Board evidence remains under `../sources/`.

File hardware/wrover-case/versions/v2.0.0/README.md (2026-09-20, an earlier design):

# WROVER case v2.0.0 — Recessed M2.5 screws

**Status: superseded. Archived prototype; not the next print candidate.**

Small screw fastening abandoned.

The versioned base and lid in `exports/` form the complete pair.

Source: `wrover-case-v2.0.0.scad`. Original notes, test coupons, previews and distribution ZIPs are preserved byte-for-byte in `../../archive/pre-versioning-originals.zip`, with original paths listed in its SHA-256 manifest. Historical instructions inside that archive may be superseded by physical feedback here.

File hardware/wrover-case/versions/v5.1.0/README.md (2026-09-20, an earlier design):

# WROVER case v5.1.0 — Internal lip, 1.0 mm hooks

**Status: partial-success. Archived prototype; not the next print candidate.**

Improved retention; still pulls off too easily.

The versioned base and lid in `exports/` form the complete pair. The base is the unchanged v5.0.0 geometry; lids v5.0.0–v6.0.0 use that base.

Source: `wrover-case-v5.1.0.scad`. Original notes, test coupons, previews and distribution ZIPs are preserved byte-for-byte in `../../archive/pre-versioning-originals.zip`, with original paths listed in its SHA-256 manifest. Historical instructions inside that archive may be superseded by physical feedback here.

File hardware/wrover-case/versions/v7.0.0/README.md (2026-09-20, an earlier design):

# WROVER case v7.0.0 — overlapping shells

**Status: user-tested. The user reports this version is “really good”.**

Follow-up: [v7.1.0](../v7.1.0/README.md) widens the cone roots and centres the vents. The halves remain interchangeable between v7.0.0 and v7.1.0. No quantified retention, thermal or endurance results have been reported. The source and meshes below remain unchanged.

This is a matched new base and lid, not a replacement lid for v5/v6. The two print files are:

- `exports/wrover-case-v7.0.0-base.stl`
- `exports/wrover-case-v7.0.0-lid.stl`

The base and lid carry recessed `W7.0.0 BASE` / `W7.0.0 LID` marks on their outside faces. Overall closed size is 86 × 46.6 × 17.6 mm, with up to 0.3 mm nominal initial lid lift against the catches. The supplied parts lie flat in print orientation. No screws, nuts, glue, metal springs or separate fastening pieces are required.

## What changed

The lid has a 4 mm deep outer skirt. It overlaps the base with 0.25 mm clearance per side. Four short beads on the base sides engage four skirt windows. The base walls are 1.6 mm thick and the skirt is 1.2 mm thick; the exposed base walls provide the intended flex for insertion and release. There are no tall isolated catch tongues or torsion arms.

Each bead projects 0.65 mm from the base wall, giving 0.40 mm nominal engagement beyond the skirt clearance. It has a gradual entry ramp and a shorter retaining bevel. The CAD release envelope uses 0.60 mm inward travel. These are prototype dimensions, not a measured release force or a strain calculation. The bevel permits removal under sufficient pull; this is not advertised as an absolute positive lock.

The PCB mounting grid, four tapered pegs, support height, four spring leaves and hollow contact feet retain the v5.1 dimensions. Three spring modules are identical in source. Their nominal free preload is 0.9 mm; initial catch contact retains approximately 0.6 mm deflection. Further elastic movement under load can change this. The PCB springs must not be joined to the skirt or filled by support material.

The approach is informed by the [maker research](../../research/other-maker-examples.md), particularly the Adafruit shell closures and YAPP overlap geometry. This is an original adaptation, not a dimension-for-dimension copy or a tested commercial latch.

## Printing and assembly

1. Print the **full base and full lid**, exterior faces on the bed, using ordinary PLA. Start with a 0.4 mm nozzle, 0.16 mm layers, 4 wall loops, 5 top/bottom layers and 20% infill. The narrow walls/leaves should be solid. Do not scale either part.
2. Inspect the slicer around the four bead undersides and the approximately 10.8 mm skirt-window bridges. The small retaining bevel is intended to print without supports; its finish matters. Avoid automatic supports inside the spring slots and peg sockets. Remove strings or elephant foot that obstruct the seam.
3. Lower the PCB onto its original peg pattern, USB at the open end. Align the lid's button-access holes with the two buttons. Lower the lid vertically and press near each catch in turn. Stop if the walls whiten or closure needs heavy force.
4. To open, press the exposed long base walls inward just below the lid skirt, near the catches, while lifting that end gently. A fingernail through a skirt window can also press a bead inward. Release the other end next. Physical testing will establish whether this action is comfortable and sufficiently secure.
5. With the PCB fitted, check all four catches, USB plug access and button access. Confirm that ordinary handling does not release the lid, then gently shake with the cable disconnected to check for board rattle. Recheck after a day closed to assess retained board pressure. Report retention, insertion/release effort and any movement separately.

## Verification and limits

See `geometry-results.json` for the actual geometric-check results. Checks cover closed fit, the rigid insertion path, approximate component envelopes, catch overlap on both sides, locating stops and an inward-shifted bead release envelope. The release check is not a simulation of a bending wall. The pressure feet intentionally overlap the unloaded PCB model because they deflect in service.

`../../tools/verify_meshes.py` checks the exported STLs for one connected, closed, consistently oriented manifold and a flat z=0 printing position. These checks do not establish PLA strength, fatigue life, dimensional accuracy, latch holding force or rattle-free performance. Those require the full physical test.

## Rebuild

From this directory:

```sh
openscad -o exports/wrover-case-v7.0.0-base.stl -D 'part="base"' wrover-case-v7.0.0.scad
openscad -o exports/wrover-case-v7.0.0-lid.stl -D 'part="lid"' wrover-case-v7.0.0.scad
python3 ../../tools/verify_meshes.py exports/wrover-case-v7.0.0-base.stl exports/wrover-case-v7.0.0-lid.stl
python3 verify_geometry.py
```

The source also provides `layout`, `assembled` and `exploded` views. Future geometry changes must receive a new version rather than silently replacing these files after this candidate is delivered.

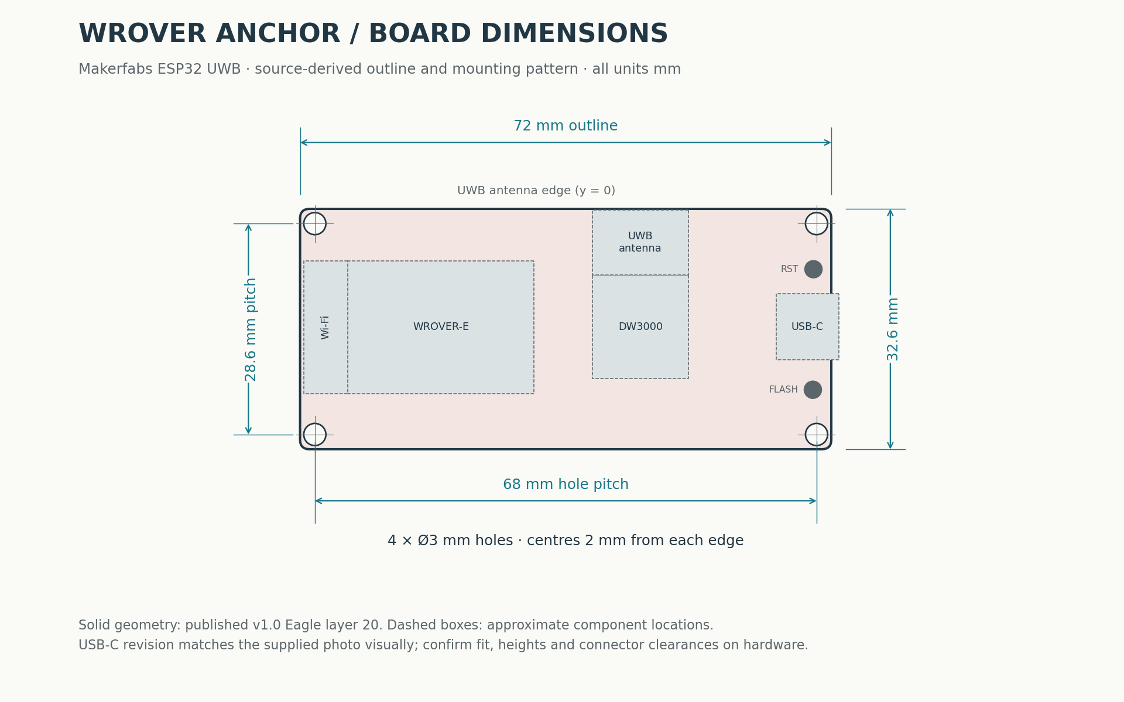
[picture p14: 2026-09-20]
hardware/wrover-case/sources/board-dimensions.png

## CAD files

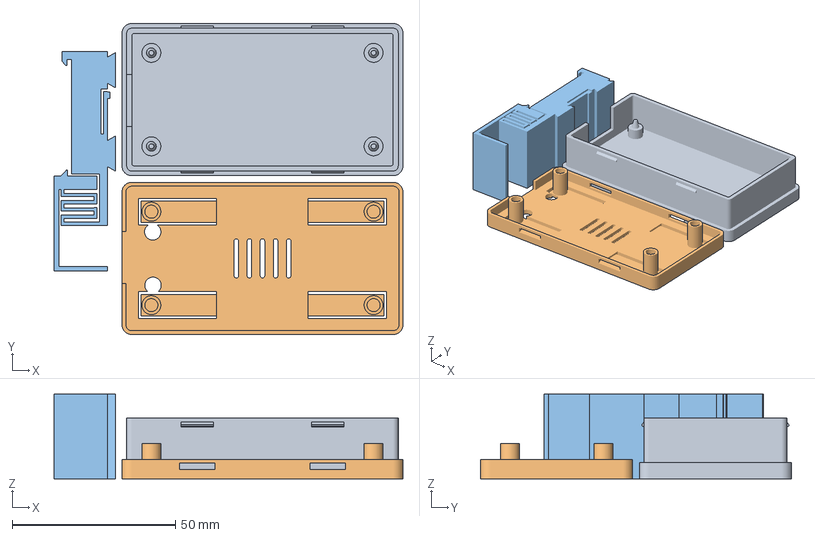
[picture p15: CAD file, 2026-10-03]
hardware/wrover-case/makerworld/wrover-case-din-rail/wrover-case-din-rail-v7.2.0.3mf
106.8 x 95.2 x 26.0 mm
Base v7.2.0 (DIN plinth)
Lid v7.2.0
DIN rail clip v7.2.0

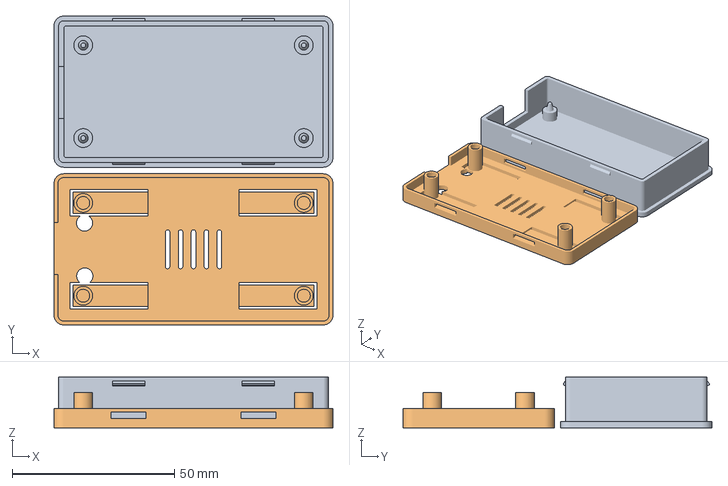
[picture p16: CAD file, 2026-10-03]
hardware/wrover-case/makerworld/wrover-case-standalone/wrover-case-standalone-v7.1.0.3mf
86.0 x 95.2 x 15.6 mm
Base v7.1.0
Lid v7.1.0

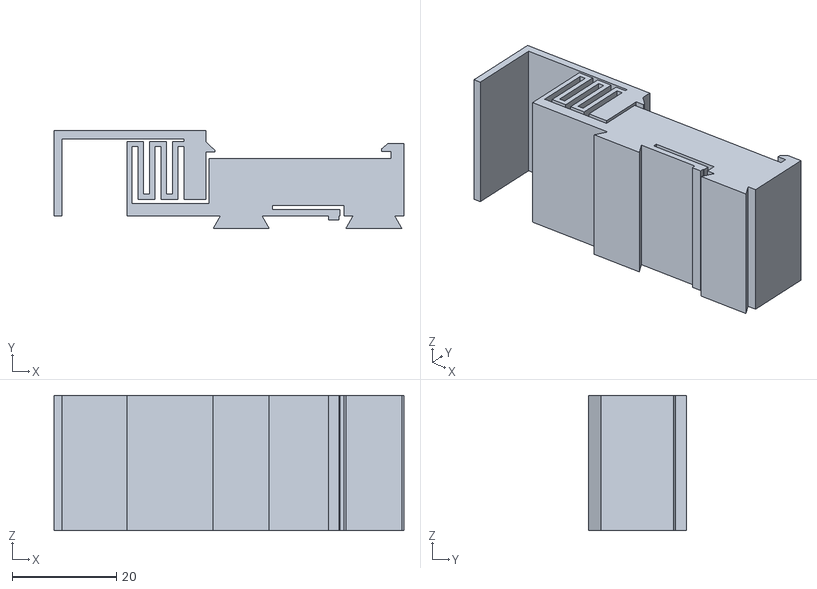
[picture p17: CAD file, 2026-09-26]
hardware/wrover-case/makerworld/wrover-case-din-rail/wrover-case-v7.2.0-din-clip.stl
67.3 x 18.8 x 26.0

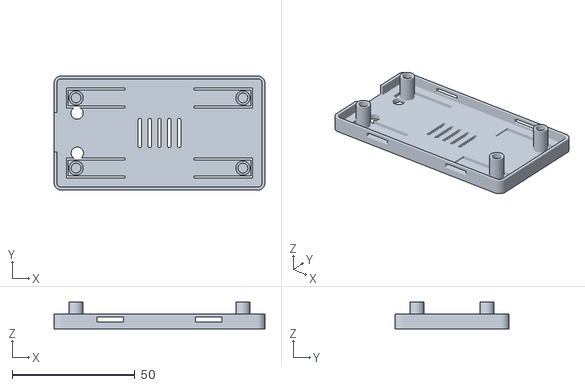
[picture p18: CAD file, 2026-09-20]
hardware/wrover-case/makerworld/wrover-case-standalone/wrover-case-v7.1.0-lid.stl
86.0 x 46.6 x 10.9

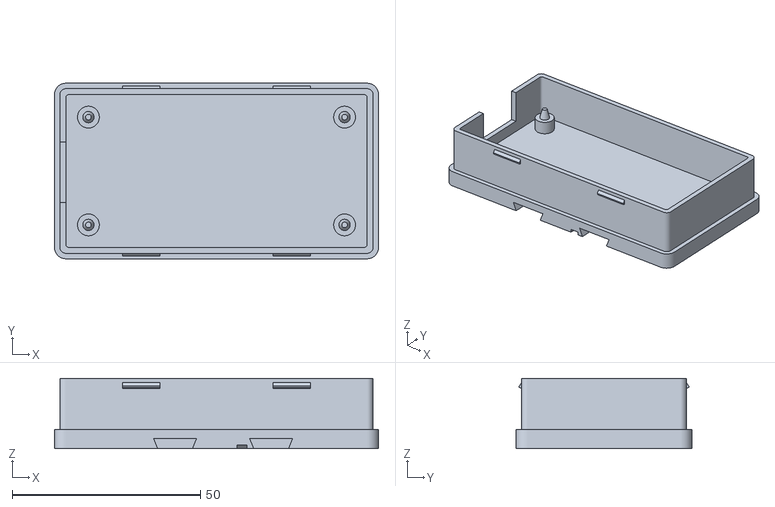
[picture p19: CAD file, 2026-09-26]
hardware/wrover-case/makerworld/wrover-case-din-rail/wrover-case-v7.2.0-base.stl
86.0 x 46.6 x 18.6

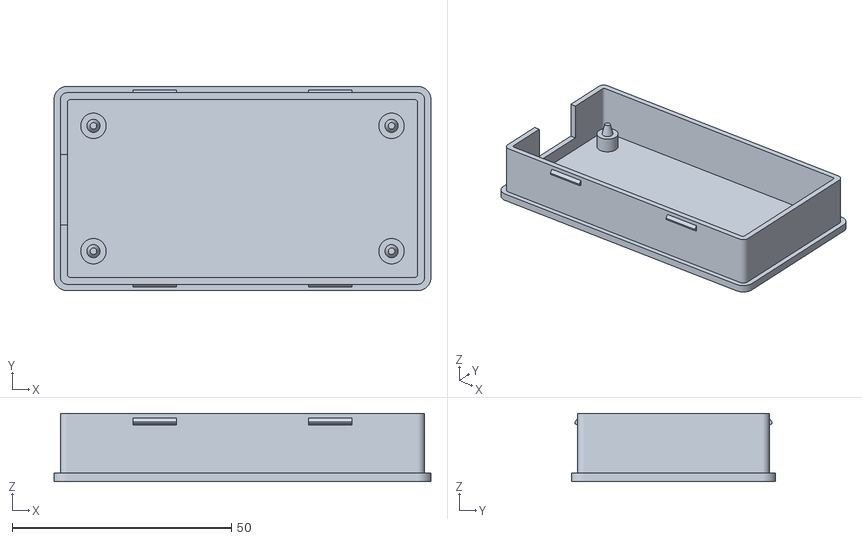
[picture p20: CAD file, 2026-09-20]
hardware/wrover-case/makerworld/wrover-case-standalone/wrover-case-v7.1.0-base.stl
86.0 x 46.6 x 15.6

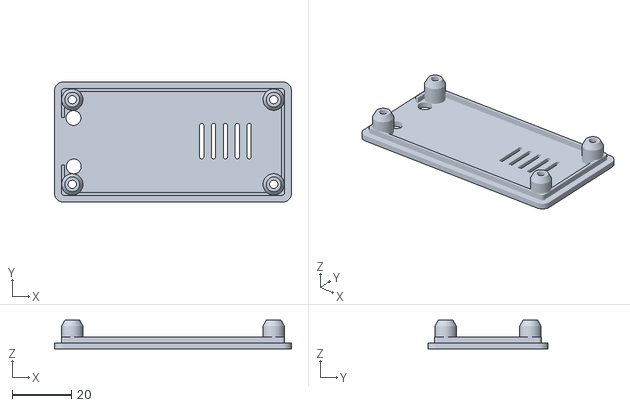
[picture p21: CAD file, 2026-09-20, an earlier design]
hardware/wrover-case/versions/v2.0.0/exports/wrover-case-v2.0.0-lid.stl
80.0 x 40.6 x 9.75

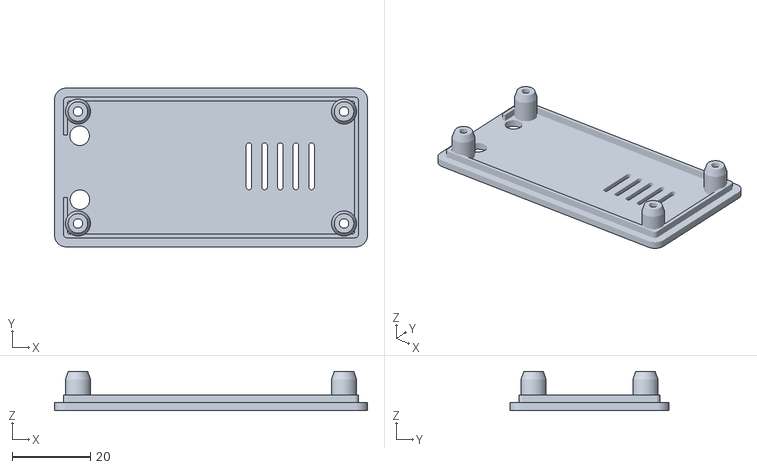
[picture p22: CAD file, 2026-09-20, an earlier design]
hardware/wrover-case/versions/v3.0.0/exports/wrover-case-v3.0.0-lid.stl
80.0 x 40.6 x 10.0

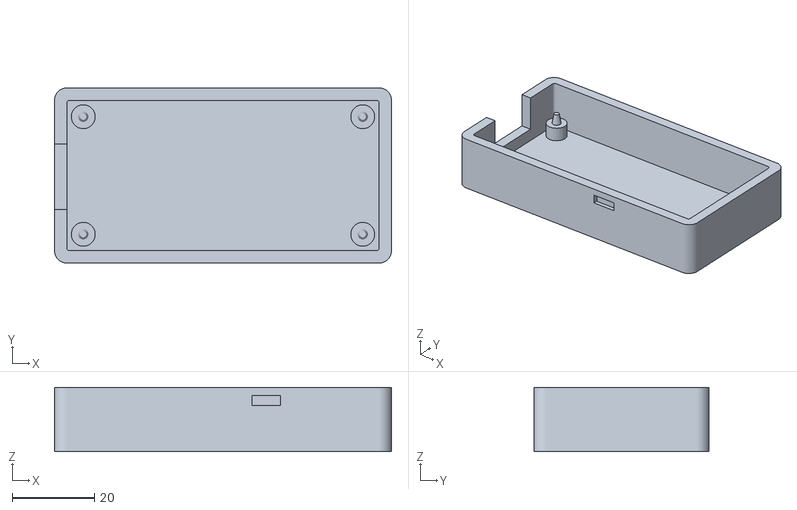
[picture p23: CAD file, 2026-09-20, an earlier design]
hardware/wrover-case/versions/v4.0.0/exports/wrover-case-v4.0.0-base.stl
82.0 x 42.6 x 15.6

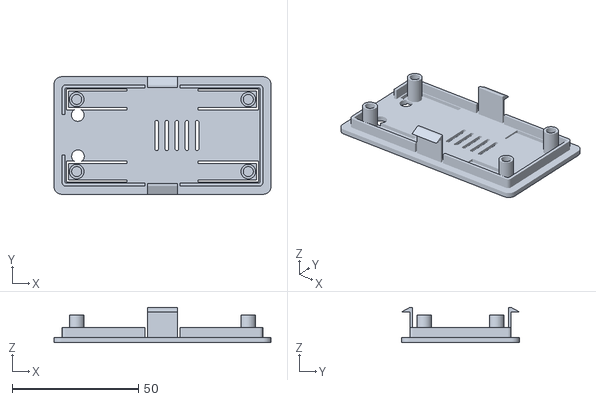
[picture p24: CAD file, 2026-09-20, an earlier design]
hardware/wrover-case/versions/v5.2.0/exports/wrover-case-v5.2.0-lid.stl
86.0 x 46.6 x 14.0

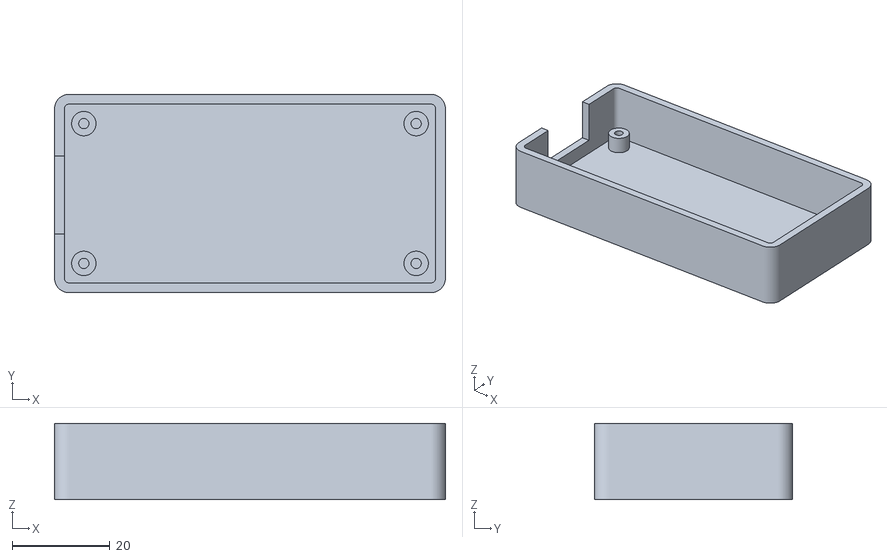
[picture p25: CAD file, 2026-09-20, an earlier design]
hardware/wrover-case/versions/v2.0.0/exports/wrover-case-v2.0.0-base.stl
80.0 x 40.6 x 15.6

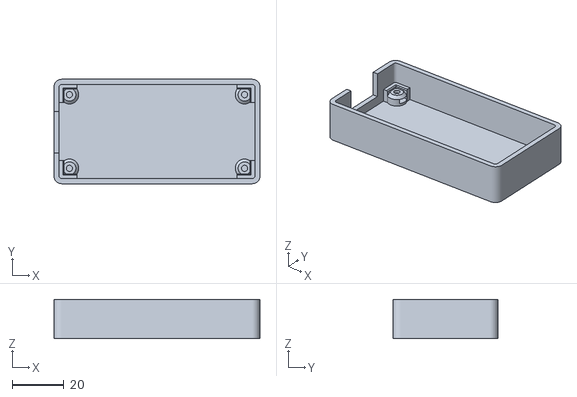
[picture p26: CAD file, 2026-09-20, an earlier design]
hardware/wrover-case/versions/v3.0.0/exports/wrover-case-v3.0.0-base.stl
80.0 x 40.6 x 15.3

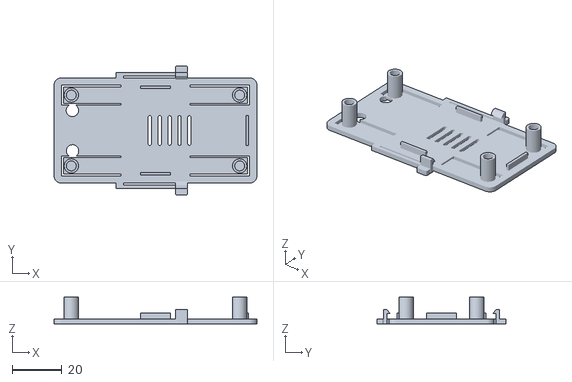
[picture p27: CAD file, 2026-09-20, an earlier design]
hardware/wrover-case/versions/v4.0.0/exports/wrover-case-v4.0.0-lid.stl
82.0 x 52.2 x 10.9

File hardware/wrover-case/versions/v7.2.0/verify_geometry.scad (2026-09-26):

// Geometric checks only, not a PLA force/strain simulation.
include <wrover-case-v7.2.0.scad>
check = "closed";
module skirt_assembled(lift=0) {
    translate([0,outer_w,total_h+lift]) rotate([180,0,0]) lid_skirt();
}
if(check=="closed") intersection() { base(); lid_assembled(); }
if(check=="rigid_insertion") for(lift=[0:0.5:16])
    intersection() { base_without_beads(); lid_assembled(lift); }
if(check=="components") intersection() {
    lid_assembled();
    intersection() {
        board_mockup();
        translate([-10,-10,pcb_top+eps]) cube([outer_l+20,outer_w+20,30]);
    }
}
// Each side separately must have a positive overlap on attempted upward pull.
if(check=="catch_left" || check=="catch_right") intersection() {
    base_beads(); skirt_assembled(clip_lift_clearance+0.2);
    translate([-1,check=="catch_left" ? -1 : outer_w/2,-1])
        cube([outer_l+2,outer_w/2+1,total_h+2]);
}
// Translate the beads inward as a clearance envelope; not an elastic solution.
if(check=="release") for(lift=[0:0.5:16]) intersection() {
    base_beads(release_travel); skirt_assembled(lift);
}
if(check=="release_board") intersection() {
    base_beads(release_travel); board_mockup();
}
// At rounded corners clearance is radial: 0.20 on axes, 0.212 on diagonals.
if(check=="allowed_play") for(p=[[0.2,0],[-0.2,0],[0,0.2],[0,-0.2],
                                    [0.15,0.15],[0.15,-0.15],[-0.15,0.15],[-0.15,-0.15]]) intersection() {
    base(); translate([p[0],p[1],0]) lid_assembled();
}
if(check=="locating_x") for(sign=[-1,1]) intersection() {
    base_without_beads(); translate([sign*(alignment_clearance+0.15),0,0]) skirt_assembled();
}
if(check=="locating_y") for(sign=[-1,1]) intersection() {
    base_without_beads(); translate([0,sign*(alignment_clearance+0.15),0]) skirt_assembled();
}

// Actual solid PCB slab (without approximate components). Seating on the posts
// is intentional surface contact; the cones must not occupy PCB material.
// Ignore 0.001 mm at the exact coincident seating face to avoid CGAL slivers.
// Nominal cone diameter at that plane is separately checked analytically.
module pcb_slab() {
    translate([ox,oy,pcb_z+0.001]) difference() {
        rounded_prism(pcb_length,pcb_width,pcb_thickness-0.001,1.25);
        for(p=holes) translate([p[0],p[1],-eps])
            cylinder(d=pcb_hole_d,h=pcb_thickness+2*eps);
    }
}
if(check=="board_seating") intersection() { base(); pcb_slab(); }

// ---- DIN rail mount (v7.2.0) ----
// Coincident seating faces are separated by 0.001 mm to avoid CGAL slivers.
module din_half(fixed) {
    translate([fixed ? rail_x : rail_x-100,-50,-100]) cube([100,outer_w+100,100]);
}
module latch_released() {
    din_place() translate([-din_release_travel,0]) linear_extrude(din_width) din_latch_2d();
}
if(check=="din_seated") intersection() {
    base_din(); translate([0,0,-0.001]) din_clip_assembled();
}
// Sliding the clip in along Y: tongues, grooves and body sweep; ridge sprung down.
if(check=="din_slide_path") intersection() {
    base_din();
    translate([0,0,-0.001]) din_place(-5) linear_extrude(din_y1+5) din_clip_2d(false);
}
if(check=="din_end_stop") intersection() {
    base_din();
    translate([0,0,-0.001]) din_place(-5)
        linear_extrude(din_y1+5+groove_end_clearance+0.2) din_clip_2d(false);
}
// Backing out 0.6 mm must meet the pocket's retaining ramp.
if(check=="din_detent") intersection() {
    base_din();
    translate([0,0,-0.001]) din_place(din_y0-0.6) linear_extrude(din_width)
        translate([detent_ridge[0],-detent_rise])
            square([detent_ridge[1]-detent_ridge[0],detent_rise]);
}
if(check=="din_rail_seated") intersection() { din_clip_assembled(); rail_mockup(0.001); }
if(check=="din_hook_fixed" || check=="din_hook_latch") intersection() {
    din_clip_assembled();
    rail_mockup(max(din_fixed_clearance,din_latch_clearance)+0.2);
    din_half(check=="din_hook_fixed");
}
// Latch pulled outward by its release travel: the rail passes straight by.
if(check=="din_latch_path") for(dv=[0:0.5:16]) intersection() {
    latch_released(); rail_mockup(dv);
}
// The pulled latch block and tab must not hit the rigid body or the case.
if(check=="din_latch_free") intersection() {
    latch_released();
    union() { base_din(); din_place() linear_extrude(din_width) din_body_2d(); }
}

// Mid-rail hook-on path, run in reverse as removal. 2D cross-section checks:
// the clip is a prism along the rail. Pivot is at the fixed-hook throat.
// Extruded only so the STL-based runner can report an empty result.
din_tilt = 10;
module din_tilted(a,latch_x=0) {
    translate([din_throat,latch_lip_top-din_latch_clearance]) rotate(a)
        translate([-din_throat,-(latch_lip_top-din_latch_clearance)]) union() {
            din_body_2d(); din_spring_2d(); translate([latch_x,0]) din_latch_2d();
        }
}
// Latch pulled by its release travel, case tilted about the fixed hook to 10 degrees.
if(check=="din_tilt_rotate") for(a=[0:1:din_tilt]) linear_extrude(1) intersection() {
    din_tilted(a,-din_release_travel); translate([0,0.001]) rail_2d();
}
// At 10 degrees, with the latch at rest: shift towards the fixed end, then lift off.
if(check=="din_tilt_unhook") for(dx=[0:0.25:1.8], dv=[0:0.25:12]) linear_extrude(1) intersection() {
    translate([dv>0 ? 1.8 : dx,-dv]) din_tilted(din_tilt);
    translate([0,0.001]) rail_2d();
}

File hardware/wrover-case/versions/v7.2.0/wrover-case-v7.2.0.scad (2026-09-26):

// Makerfabs ESP32 UWB DW3000 / WROVER-E case v7.2.0, millimetres.
// EXPERIMENTAL: DIN rail mount added to the accepted v7.1.0 case.
// Overlapping shells with four low-profile beads, inspired by the maker
// references in ../../research/other-maker-examples.md. Original geometry.
// v7.2: 3 mm dovetail plinth under the unchanged v7.1.0 base floor, plus a
// separate snap-on TS35 (EN 60715 35 x 7.5) clip. The lid is unchanged from v7.1.0.
// Print base and lid exterior-face down; print the clip on its side (profile down).

/* [View] */
part = "layout"; // [layout,base,lid,din_clip,assembled,exploded]
show_board = true;

/* [PCB] */
pcb_length = 72;
pcb_width = 32.6;
pcb_thickness = 1.6;
pcb_hole_d = 3;
hole_inset = 2;
under_board = 4;
above_board = 8;

/* [Shell] */
// PCB origin is independent of the thinner shell: preserve the proven hole grid.
wall = 3; // Legacy coordinate offset only; see shell_wall for physical wall.
edge_gap = 4;
floor_thickness = 2;
lid_thickness = 2;
corner_radius = 3;
shell_wall = 1.6;
lip_wall = 1.2;
alignment_clearance = 0.25;
lip_depth = 4;

/* [Board location and anti-rattle springs] */
post_d = 5.8;
// Nominal line contact at the lower PCB-hole rim; no designed interference.
// Root diameter is measured AT pcb_z, not at the buried CSG overlap.
pin_root_d = pcb_hole_d;
pin_tip_d = 1.5;
pin_height = 3;
// Free contact pads extend below nominal PCB top by this amount.
// With 0.3 mm latch lift, nominal retained spring deflection is 0.6 mm.
board_preload = 0.9;
board_spring_length = 20;
board_spring_width = 6.6;
board_spring_thickness = 1.2;
slot_width = 0.8;
pin_socket_d = 4;
pin_socket_depth = 3.6;

/* [Distributed shell catches] */
bead_width = 10;
bead_projection = 0.65; // Net engagement into lid skirt = 0.40, not 3 mm.
bead_bottom = 12.9;
bead_lower_rise = 0.32; // Short retaining bevel; inspect these layers in slicer.
bead_land = 0.38;
bead_entry_rise = 0.9;
window_side_clearance = 0.4;
clip_lift_clearance = 0.3;
release_clearance = 0.2;
version_marks = true;

/* [USB and buttons] */
usb_y = 16;
usb_width = 16;
usb_bottom_offset = -2;
button_access = true;
reset_x = 2.4166;
reset_y = 8.1851;
flash_x = 2.5;
flash_y = 24.532;
button_access_d = 5;
vents = true;

/* [DIN rail mount] */
// The rail runs along the case width (Y). Fixed hook at the far end, sprung
// latch and pull tab at the USB end, so the USB end faces down on a level rail.
din_mount = true;
plinth_h = 3; // Added below the unchanged floor; carries the dovetail grooves.
rail_width = 35;
rail_lip = 1;
rail_depth = 7.5;
rail_crown_w = 27;
din_width = 26; // Clip length along the rail.
din_standoff = 11; // Plinth to rail front face; sets the spring beam length.
din_edge_clearance = 0.3;
din_fixed_clearance = 0.4; // Extra room to rock the fixed hook on first.
din_latch_clearance = 0.25;
din_hook_reach = 1.5;
din_hook_wall = 2.5;
din_block_w = 4.2;
din_top_bar = 2.4;
din_spring_beams = 5; // Odd count: anchored at the top bar, ends at the block.
din_spring_t = 1;
din_spring_gap = 1.2;
din_tab_t = 1.6;
din_pull_gap = 2.5; // Screwdriver/fingernail slot beyond the case end.
din_pull_t = 1.5;
dovetail_x = [-11, 14.5]; // Relative to the rail centre line.
dovetail_neck = 8;
dovetail_depth = 2.4;
dovetail_angle = 30;
dovetail_clearance = 0.2;
groove_end_clearance = 0.3;
// Sprung detent finger: its ridge drops into a plinth pocket at full insertion.
detent_finger = [-5, 8];
detent_ridge = [5.8, 7.8];
detent_rise = 0.8;
detent_pocket_depth = 1;
detent_finger_t = 1.2;
detent_slot = 0.8;
detent_entry_run = 3;

/* [Hidden] */
$fn = 64;
eps = 0.02;
ox = wall + edge_gap;
oy = wall + edge_gap;
outer_l = pcb_length + 2*ox;
outer_w = pcb_width + 2*oy;
pcb_z = floor_thickness + under_board;
pcb_top = pcb_z + pcb_thickness;
body_h = pcb_top + above_board;
total_h = body_h + lid_thickness;
foot_h = total_h - pcb_top + board_preload;
base_inset = lip_wall + alignment_clearance;
base_inner = base_inset + shell_wall;
bead_top = bead_bottom+bead_lower_rise+bead_land+bead_entry_rise;
bead_contact_z = bead_bottom + bead_lower_rise*alignment_clearance/bead_projection;
window_bottom = bead_contact_z-clip_lift_clearance;
window_top = bead_top+0.2;
bead_centres = [23, outer_l-23];
release_travel = bead_projection-alignment_clearance+release_clearance;
holes = [[hole_inset,hole_inset], [pcb_length-hole_inset,hole_inset],
         [pcb_length-hole_inset,pcb_width-hole_inset],
         [hole_inset,pcb_width-hole_inset]];
// DIN clip profile: x across the rail from its centre line (+x towards the far
// case end), v from the plinth underside towards the mounting panel.
rail_x = outer_l/2;
din_y0 = (outer_w-din_width)/2;
din_y1 = din_y0+din_width;
groove_end = din_y1+groove_end_clearance;
rail_edge = rail_width/2;
din_throat = rail_edge+din_edge_clearance;
din_body_end = -(din_throat-2*din_edge_clearance); // Rigid body stops short of latch.
fixed_lip_top = din_standoff+rail_lip+din_fixed_clearance;
latch_lip_top = din_standoff+rail_lip+din_latch_clearance;
lip_tip = rail_edge-din_hook_reach;
din_block_outer = -din_throat-din_block_w;
din_turn_v = din_top_bar+0.8;
din_spring_bottom = latch_lip_top+din_hook_reach+0.55;
din_tab_top = din_spring_bottom+0.5;
din_tab_bottom = din_tab_top+din_tab_t;
function beam_face(i) = din_block_outer-din_spring_gap*i-din_spring_t*(i-1);
din_spring_outer = beam_face(din_spring_beams)-din_spring_t;
din_pull_inner = -rail_x-din_pull_gap;
dovetail_top = dovetail_neck+2*dovetail_depth*tan(dovetail_angle);
din_release_travel = din_hook_reach+din_edge_clearance-0.1;

assert(base_inner < oy+hole_inset-board_spring_width/2-slot_width-0.2);
assert(lip_wall < ox+hole_inset-4-slot_width);
assert(pin_root_d <= pcb_hole_d && pin_tip_d < pin_root_d);
assert(pin_socket_depth > pin_height-pcb_thickness+board_preload+0.5);
assert(board_preload > clip_lift_clearance+0.3);
assert(bead_projection > alignment_clearance && bead_projection < lip_wall);
assert(window_bottom > body_h-lip_depth+0.8);
assert(window_top < body_h-0.8);
assert(base_inner+release_travel < oy-post_d/2);
assert(din_spring_beams%2==1);
assert(din_spring_outer > din_pull_inner+2);
assert(din_tab_bottom < din_standoff+rail_depth-1);
assert(dovetail_depth+dovetail_clearance < plinth_h-0.3);
assert(detent_pocket_depth > detent_rise && detent_pocket_depth < plinth_h-1);
assert(detent_ridge[1] < detent_finger[1] &&
       detent_finger[1]+detent_slot < dovetail_x[1]-dovetail_top/2);
assert(detent_finger[0] > dovetail_x[0]+dovetail_top/2);
assert(din_y0-detent_pocket_depth-0.2 > detent_entry_run+1);
echo(str("v7.2.0 closed case: ",outer_l," x ",outer_w," x ",total_h+(din_mount ? plinth_h : 0),
         " mm; clip ",din_pull_inner-din_pull_t+rail_x," to ",din_throat+din_hook_wall+rail_x,
         " mm along the case, ",din_width," mm along the rail"));
echo(str("DIN latch travel to clear the rail edge: ",din_release_travel," mm"));
echo(str("Net bead engagement: ",bead_projection-alignment_clearance,
         "; clearance-envelope release: ",release_travel," mm"));
echo(str("Nominal retained PCB spring deflection: ",board_preload-clip_lift_clearance));
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

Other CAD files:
hardware/wrover-case/versions/v5.0.0/exports/wrover-case-v5.0.0-base.stl
hardware/wrover-case/versions/v5.1.0/exports/wrover-case-v5.1.0-base.stl
hardware/wrover-case/versions/v6.0.0/exports/wrover-case-v6.0.0-base.stl
hardware/wrover-case/versions/v7.0.0/exports/wrover-case-v7.0.0-lid.stl
hardware/wrover-case/versions/v2.0.0/wrover-case-v2.0.0.scad
hardware/wrover-case/versions/v3.0.0/wrover-case-v3.0.0.scad
hardware/wrover-case/versions/v4.0.0/verify_geometry.scad
hardware/wrover-case/versions/v4.0.0/wrover-case-v4.0.0.scad
hardware/wrover-case/versions/v5.0.0/exports/wrover-case-v5.0.0-lid.stl
hardware/wrover-case/versions/v5.0.0/verify_geometry.scad
hardware/wrover-case/versions/v5.0.0/wrover-case-v5.0.0.scad
hardware/wrover-case/versions/v5.1.0/exports/wrover-case-v5.1.0-lid.stl
hardware/wrover-case/versions/v5.1.0/verify_geometry.scad
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

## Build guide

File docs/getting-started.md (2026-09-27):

# Getting started

BinRange currently expects embedded-development experience. It is a field
prototype, not a one-click Home Assistant integration. No deployable prebuilt
images or signing keys are distributed.

## What you need

- Compatible ESP32-WROVER/DW3000 anchor and K4W nRF52833/DW3110 tags.
- Stable permanent anchor power and Wi-Fi coverage.
- MQTT broker and Home Assistant; tags do not connect directly to Wi-Fi.
- SWD programmer for each tag's first installation and recovery.
  The [Nesso probe](../firmware/nesso-probe/README.md) is an optional implementation.
- PlatformIO for the anchor/emulator/probe, and the pinned Nordic/Zephyr toolchain
  in the [tag build guide](../firmware/k4w-tag/BUILD.md).
- Your own private signing key, admin password and tag identity register.

Review [hardware and power](hardware.md) before wiring. Never supply a tag from
its battery and programmer VDD simultaneously. Verify board identity and voltage,
not just a photograph of a similar board.

## Setup sequence

1. **Prepare the broker and anchor.** Copy the anchor's `secrets.h.example` to
   ignored `secrets.h` and set your own Wi-Fi and first-boot broker values.
   Generate private admin bootstrap input as specified in [tag updates](tag-updates.md).
   Build from the repository root with `pio run -d firmware/anchor -e anchor`.
   This builds; it does not flash. Inspect the selected physical board before
   any upload. Broker credentials can subsequently be changed in the web UI.
2. **Build and verify a signed tag image.** Follow the SDK/partition/preflight
   instructions; keep the signing key backed up outside Git and off the anchor.
   Never use someone else's provisioned binary or silently replace an installed
   bootloader/signing key.
3. **Commission one tag at a time.** Record casing label ↔ immutable chip ID ↔
   firmware BLE address ↔ UWB ID ↔ chosen name in private local storage.
   First installation can erase factory software; decide deliberately whether
   to preserve it. Provisioning is not an ordinary firmware update.
4. **Adopt and pair separately.** MQTT adoption creates the HA device;
   authenticated BLE commissioning authorizes maintenance. UWB reporting alone
   proves neither pairing nor a successful update.
5. **Check real reports in HA.** Verify distance, reception time, motion, voltage
   and health belong to the right device. Configure a daily dashboard and a
   diagnostic view using actual discovered entities, not assumed names.
6. **Configure collection schedules.** Install
   [Waste Collection Schedule via HACS](https://github.com/mampfes/hacs_waste_collection_schedule/blob/master/doc/installation.md)
   and select your own provider/calendar. Map its collection categories to your
   tags. One category may correspond to multiple bins.
7. **Validate the installed site.** Measure storage/collection distances and
   obstruction effects. Choose a useful threshold with margin; treat stale
   readings as Unknown. Only then enable position-aware reminders.

## Local/private configuration

Keep these out of Git:

| Data | Suggested local location |
| --- | --- |
| Wi-Fi / first-boot broker configuration | `firmware/<target>/src/secrets.h` |
| HA access token | `.ha-token` or a private credential store |
| Admin bootstrap / recovery secret | Ignored file supplied to the build by path |
| Signing key and provisioned images | `local-backups/`, with separate secure backup |
| Programmer profile / protected chip IDs | `local-backups/programmer.json` |
| Household dashboard helpers / entity mappings | Private deployment tooling |
| Tag/casing register, observations, photos | `local-backups/deployment/` |

Examples use synthetic identifiers and placeholder hosts. Configure tools
explicitly for your equipment. The optional programmer profile must include a
nonempty `protected_hardware_ids` list: immutable chip IDs that must never be
treated as new first-install targets. Missing protection data must fail closed.

The firmware can range without HA, but alerts obviously cannot operate during
an HA/broker outage. Keep the maintenance HTTP/MQTT endpoints on a trusted LAN;
they are not designed for direct Internet exposure.

## Before relying on it

Use [the roadmap](current-work.md) as an acceptance checklist. A few successful
bench exchanges are not a field battery-life, ingress-protection or unattended
OTA guarantee. Keep a known-good signed release and a tested recovery method.

## Host-side checks

Run `pio test -d firmware/anchor -e native` for the Arduino-free core. Python
checks live in `scripts/test_*.py`; run the `test_k4w*.py` and `test_anchor*.py`
groups with `python -m unittest discover -s scripts -p 'PATTERN'`.
These checks do not flash hardware.

The web-page regression test also requires Node.js on `PATH`. It executes the
shipped JavaScript with a simulated page and HTTP responses, without a device.

The anchor integration tests compile against the installed PlatformIO framework
and pinned NimBLE library. Build the anchor first to obtain them. Set
`BINRANGE_NIMBLE_REFERENCE` to a separate, unmodified NimBLE-Arduino 2.5.1 source
directory: the tests verify upstream hashes before exercising the build patches.
`BINRANGE_PLATFORMIO_PACKAGES` can override the default
`~/.platformio/packages` location. The optional probe tests require its separately
downloaded upstream source; SDK image-preflight tools need their documented
Python dependencies.

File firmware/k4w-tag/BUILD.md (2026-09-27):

# Signed tag firmware: build and recovery

Experimental integration candidate. Signed BLE updates, local confirmation,
watchdog rollback and motion/sleep behavior have been exercised; complete
field/battery/unattended-OTA acceptance is still open. See
[findings](../../docs/findings.md) and [roadmap](../../docs/current-work.md).

## Toolchain and key

`west.yml` pins Nordic nRF Connect SDK v3.3.0 and matching Zephyr. The tested
toolchain was Zephyr SDK 0.17.4 / ARM GCC 12.2.0, west 1.5.0, CMake 4.4.3 and
Ninja 1.13.2. Obtain the SDK separately and verify effective generated configs.

Use your own private ECDSA-P256 signing key, stored outside Git and securely
backed up. Losing it prevents signing future images accepted by that bootloader.
Never replace an installed key silently. The anchor never receives the private
key; the bootloader contains the public key.

Set paths for your checkout, SDK workspace, SDK tools, fresh build directory and
private key. The following is a **build**, not an upload:

```sh
# Replace these paths with your own; do not reuse someone else's signed image.
BINRANGE_ROOT=/absolute/path/to/BinRange
NCS_ROOT=/absolute/path/to/ncs
BUILD_DIR=/absolute/path/to/new-build
SIGNING_KEY=/absolute/path/to/private-signing-key.pem
ZEPHYR_SDK_INSTALL_DIR=/absolute/path/to/zephyr-sdk-0.17.4
export ZEPHYR_SDK_INSTALL_DIR
export ZEPHYR_TOOLCHAIN_VARIANT=zephyr
cd "$NCS_ROOT"
west build --sysbuild -b k4w/nrf52833 -d "$BUILD_DIR" \
  "$BINRANGE_ROOT/firmware/k4w-tag" -- \
  -DBOARD_ROOT="$BINRANGE_ROOT/firmware/k4w-tag" \
  -DBINRANGE_RADIO_DIAGNOSTIC=OFF \
  '-Dk4w-tag_CONF_FILE=prj.conf;ota.conf' \
  -DDTC_OVERLAY_FILE="$BINRANGE_ROOT/firmware/k4w-tag/ota.overlay" \
  -Dmcuboot_DTC_OVERLAY_FILE="$BINRANGE_ROOT/firmware/k4w-tag/sysbuild/mcuboot.overlay" \
  "-DSB_CONFIG_BOOT_SIGNATURE_KEY_FILE=\"$SIGNING_KEY\"" \
  -DEXTRA_ZEPHYR_MODULES="$BINRANGE_ROOT/firmware/k4w-tag/modules/recovery"
```

Ensure the SDK environment provides the pinned tools before running west.
The bootloader overlay selects its partition at zero; the application selects
the primary slot. Do not pass the application's chosen partition to MCUboot.
The diagnostic CMake option uses `zephyr_get` for sysbuild. MCUmgr requires
NET_BUF/ZCBOR explicitly; inspect generated configuration, not only input files.

## Installed partition contract

| Region | Start | Size |
| --- | --- | --- |
| Bootloader | 0x00000 | 0x10000 |
| Primary | 0x10000 | 0x35000 |
| Secondary | 0x45000 | 0x36000 |
| Settings | 0x7b000 | 0x05000 |

Offset swap reserves the secondary's first 4 KiB. Image allowance after the
primary trailer is **212992 bytes**, including header/TLVs. BIN and HEX are
separately signed and signature lengths may differ. Inspect both exact artifacts.
Do not hand-write an image to the secondary base; use the SDK image manager.

LTO requires `CONFIG_ISR_TABLES_LOCAL_DECLARATION=y`; both must be effective.
The integrated candidate otherwise exceeds the signed slot. Never silently
repartition an installed tag or install a newly generated bootloader merely
because sysbuild produced one.

## Preflight and first installation

Run `scripts/k4w_ota_preflight.py BUILD_DIR` with the SDK Python, without `-O`.
It checks configs, exact HEX ranges/pages, signed size and RAM handoff against
both ELFs. Also verify both signed BIN and HEX using SDK imgtool and your key.
Layout tests are not signature verification.

Use the guarded [programmer](../nesso-probe/README.md#first-install-command) for
a deliberately selected new unit. Record casing/immutable chip identity privately;
decide whether to preserve original firmware before any erase/unlock.
A prior first-install permission never authorizes erasing an established tag.

Provisioning requires an identity-guarded reset-halt and one-shot RAM request:
magic `0x42525056`, `0x53445731`, selected UWB ID, DEVICEID0, DEVICEID1.
Use the cookie address reported by preflight, **not a copied address from another
build**. It must be beyond bootloader RAM. The app consumes/clears it before
saving identity and never replaces a valid identity with a cookie.

Capture the commissioning PIN privately through physical SWD; never Git/logs.
`k4w_pair.py` pairs only the explicit selected address using a private PIN file.
Then verify the immutable chip ID with `k4w_ble.py status`. A BLE name is not
identity. Local windows expire; ordinary updates use existing bonds.

## Runtime and tuning

Normal firmware includes accelerometer delta interrupts, internal-VDD sampling,
5 s moving / 10 min idle reporting, 30 s settling and at most two five-second
retries after a locally failed idle/settled exchange. UWB sleeps between attempts;
bounded System ON wakes preserve the 20 s watchdog. The local trial stays awake
for radio/sensor health checks. A sent FINAL alone does not prove reception.

BLE advertises at 2.0–2.1 s outside the local window. Advertising restart waits
for connection recycling; callbacks wake the main owner rather than performing
HCI work. Do not weaken authentication to work around timing.
See [hardware](../../docs/hardware.md) for pin/filter/ADC constraints.

Authenticated management group 64 command 2 reads/writes tuning. Writes require
a confirmed image, secured bond, maintenance window and all five bounded integer
fields. Settings persist before main-loop application; inspect
`config_pending`/`sensor_error`. Example placeholders:

```sh
python scripts/k4w_ble.py --address TAG_BLE_ADDRESS config
python scripts/k4w_ble.py --address TAG_BLE_ADDRESS \
  --expected-id TAG_IMMUTABLE_CHIP_ID configure \
  --moving-ms 5000 --idle-ms 600000 --quiet-ms 30000 \
  --threshold-mg 250 --duration-samples 2
```

The helper uses the existing OS bond, never implicit re-pairing.
Status includes millivolts, motion, wake/IRQ counts, sensor error, local misses and
UWB sleep state. A regulated jig reading is not battery state of charge.

## Rescue boundaries

Match DEVICEID before writes. Use reset-halt, not a plain halt before the RAM
flash algorithm. Locate diagnostics from the exact ELF; addresses vary.
Never automatically replay a failed flash. Normal OTA writes inactive application
space only; preserve bootloader, UICR, identity and bonds.

Validated radio profile: channel 5, 1024-symbol preamble, 850 kb/s,
16-symbol nonstandard SFD, STS off; FINAL delay 4500 UUS in an 8000-UUS window.
Antenna delay is not universal calibration. Retain OTP trim; reset DW3110 low
then release to input rather than driving it high.

Keep known-good signed images/manifests/hashes privately. Direct-boot diagnostic
binaries are not OTA payloads or shortcuts for MCUboot-equipped tags.
Preserve vendor source notices; see [third-party notes](../../docs/third-party.md).

### Home Assistant interval controls (0.2.6+)

Use tag firmware 0.2.6+ with anchor firmware 0.2.4+ for the Home Assistant
stationary/moving interval controls described in [MQTT](../../docs/mqtt.md#changing-tag-check-in-intervals).
Group 64 command 2 and its five-field persistent record remain compatible.
Tag status adds `config_schema: 1`: `config_pending` now stays true until the
main owner has applied both the motion policy and sensor configuration. A
revision acknowledgment preserves a newer pending write arriving during that
application. `sensor_error` is checked after pending clears. Older firmware can
still be updated using the existing anchor updater, but the new interval
controller will not write to it until this stronger status contract is available.

Build and deploy the application through the existing signed-update process;
do not replace an installed bootloader or signing key. Configuration operations
persist the settings in `motion/v1` without changing provisioning or bonds.

### Tipping detection (0.2.7+)

With anchor 0.2.5+, the tag reports a persistent tipping counter and the age of
its latest tip. The first installation of this feature needs the bin upright
and stationary: 50 stable samples at 25 Hz establish its mounting reference.
That reference is saved once and survives subsequent reboots. Moving samples,
read failures and accelerations outside 0.75–1.25 g do not establish a reference.
A stationary bin that is already inverted at first setup would establish the
wrong reference; keep bins upright during initial commissioning of this feature.

The existing motion interrupt wakes the main owner, which reads unfiltered
three-axis acceleration at 25 Hz. An independent 1 Hz idle check catches gradual
tilt; leaning beyond 45 degrees promotes sampling to 25 Hz without a motion IRQ.
Three consecutive valid samples more than 90 degrees from the reference count
as a tip. Exactly 90 degrees does not. Five consecutive samples within 45 degrees
rearm the detector. Restarting while inverted does not generate another event.
The idle checks add sensor/CPU activity; whole-board battery impact is unmeasured.

The counter is saved before a new event is advertised as ready, and a new tip
requests an immediate radio report plus the existing moving report cadence.
Every subsequent report repeats the count and growing event age, so a brief
radio outage does not discard the event. Counter/reference storage errors fail
closed and are exposed by `tip_error` in authenticated BLE status. `tip_ready`,
`tip_count` and `tip_age_s` are also available there. No event since reboot uses
`UINT32_MAX` age; the anchor converts that sentinel to null. A reboot preserves
the counter/reference but cannot reconstruct the event's age without a clock.

This is a gravity-based tipping heuristic, not proof of empty contents. Spinning
an upright bin about the vertical axis does not count. Motion acceleration can
affect the angle estimate, and events shorter than the sampling/debounce window
can be missed; validate representative collection handling on the actual bins.

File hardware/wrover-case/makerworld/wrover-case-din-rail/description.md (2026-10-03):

# DIN rail case for Makerfabs ESP32 UWB DW3000 (WROVER)

This is the screwless WROVER case with a snap-on mount for standard 35 mm top-hat (TS35 × 7.5) DIN rail. It fits mid-rail like a breaker, so you don't need to slide it on from the rail end. It needs no screws, glue or supports.

- **Base**: the standalone case base on a 3 mm plinth with two dovetail grooves underneath. Closed size: 86 × 46.6 × 20.6 mm.
- **Lid**: identical to the standalone version.
- **DIN clip**: a separate part that slides into the dovetails and clicks home. It has a fixed hook at one end and a spring latch with a pull tab at the USB end.
- **On the rail**: the case takes about 2.6 modules (46.6 mm) of rail. The USB end faces down, and the front sits about 39 mm off the mounting panel.

## Files

- `wrover-case-din-rail-v7.2.0.3mf`: base, lid and clip on one plate, in print orientation
- `wrover-case-v7.2.0-base.stl`, `wrover-case-v7.2.0-lid.stl`, `wrover-case-v7.2.0-din-clip.stl`: the same parts as individual STLs

## Print settings

- 0.4 mm nozzle, 0.16 mm layers, 4 walls, 5 top and 5 bottom layers, 20% infill
- No supports. Keep the parts in the orientation they're laid out in:
  - The base and lid print outside face down.
  - The clip prints on its side, 26 mm tall, so its spring flexes along the layer lines.
- The base and lid work in PLA. PETG is the better choice for the clip's spring.
- Watch for elephant's foot on the base, because it narrows the dovetail grooves.

## Assembly

1. Fit the board and lid exactly as in the standalone case.
2. Slide the clip into the plinth grooves from the open side until it stops and clicks.
3. Put it on the rail: tilt the case about 10° and hook the fixed end over the top rail edge. Then rotate the USB end down until the latch snaps over.
4. To remove it: put a screwdriver or fingernail between the pull tab and the case. Pull the tab outward, tilt the USB end up and lift the case off.

## Status

The case itself is the maker's current working design. The DIN mount is new and has passed CAD clearance checks only; it hasn't been printed yet. Snap-on force and detent hold haven't been measured. Feedback and makes are welcome.

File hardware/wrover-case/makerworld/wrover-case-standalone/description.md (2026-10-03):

# Screwless case for Makerfabs ESP32 UWB DW3000 (WROVER)

A two-part snap-together case for the Makerfabs ESP32 UWB DW3000 board, WROVER-E version (72 × 32.6 mm PCB). It needs no screws, nuts, glue or supports.

- The lid overlaps the base and is held by four shallow snap beads. Squeeze the long sides near the catches to open it.
- Four tapered pins locate the board through its mounting holes, and four sprung pads in the lid hold it down without rattling.
- The USB port is open at one end, and there are access holes for the reset and flash buttons.
- The lid has a centred vent pattern.
- Closed size: 86 × 46.6 × 17.6 mm.

Also available as a DIN rail version, which uses the same lid with a snap-on TS35 clip.

## Files

- `wrover-case-standalone-v7.1.0.3mf`: base and lid on one plate, in print orientation
- `wrover-case-v7.1.0-base.stl`, `wrover-case-v7.1.0-lid.stl`: the same parts as individual STLs

## Print settings

- PLA, 0.4 mm nozzle, 0.16 mm layers
- 4 walls, 5 top and 5 bottom layers, 20% infill
- No supports. Print both parts outside face down, as laid out. Don't scale them.
- Keep automatic supports out of the spring slots and pin sockets in the lid.

## Assembly

1. Lower the board onto the four pins with the USB connector at the open end.
2. Line the lid's button holes up with the two buttons.
3. Press the lid straight down, near each catch in turn, until all four click.
4. To open, squeeze the long base walls just below the lid near the catches and lift that end.

The board should rest on all four supports before you close the lid. If the pins are oversized on your printer, don't force it.

## Status

The previous revision was printed and tested with the board fitted. This version adds wider locating pins and centred vents, and it is the maker's current working design. No force or endurance measurements have been made.

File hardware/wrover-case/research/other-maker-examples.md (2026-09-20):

# Screwless enclosure research for the WROVER case

Research date: 2026-09-20. This is evidence gathering, not a new design or a claim that another enclosure's dimensions transfer directly to our WROVER case.

## Strong PLA examples

### Adafruit PyGamer snap-fit case — Ruiz Brothers

The PCB rests on built-in standoffs and is captured between two snapping halves without screws. The makers describe opening it by pressing the marked edges on both sides, starting near the top. Their printing page specifies PLA, reports tests on an Ultimaker 3 and Flashforge Inventor II, requires no supports, and offers original Fusion 360 and STEP files. This is a documented physical build, not merely a CAD rendering. The display bezel uses glue, so the complete accessory is not exclusively printed assembly, but the case closure and PCB retention are screwless. No cycle-life or retention-force measurements are provided. [Assembly and overview](https://learn.adafruit.com/pygamer-snapfit-case?view=all), [printing and source files](https://learn.adafruit.com/pygamer-snapfit-case/3d-printing), [linked download](https://www.thingiverse.com/thing:3686964).

**Relevance:** A vertical assembly can capture the PCB and let the case edges provide the release action. We should inspect the original geometry before copying exact latch dimensions; text alone does not establish hook angles or deformation paths.

An independent published make by Lucina reports that the case fits well and prints easily. The make does not identify filament or quantify latch strength. The documented squeeze-to-open procedure is useful evidence of intentional release behavior, but does not prove it cannot also be pulled apart. Direct model downloads could not be inspected during this pass, so no claim is made about exact retaining-face angles. [Independent make](https://cults3d.com/en/3d-printing/pygamer-snap-fit-case), [creator's opening instructions](https://learn.adafruit.com/pygamer-snapfit-case/assembly).

### Adafruit Fruit Jam case — Noe Ruiz

The enclosure requires no hardware fasteners. Assembly places the PCB on locating standoffs, then presses the upper and lower halves together. The maker explicitly reports PLA/FDM testing and publishes Fusion 360/STEP source plus 3MF files. Their reference settings include 0.2 mm layers, 0.42 mm lines, and two wall loops. They also warn that the parts have tight tolerances. The guide includes assembly photographs, but does not publish retention-force or fatigue data. [Creator's guide, CAD links and assembly](https://learn.adafruit.com/fruit-jam-case?view=all).

**Relevance:** Confirms that a hardware-free PCB enclosure in ordinary PLA is practical. It does not establish that the same closure will remain secure under our lid's four continuously loaded PCB springs.

### Circuit Playground case — Ruiz Brothers (closure-only precedent)

This design has nubs on the inside edges mating with recesses in an overlapping lip. The creator reports PLA testing and provides STL and editable CAD downloads. Its board is attached with M3 screws, so it is an example of a screwless **case closure**, not an entirely screwless enclosure. [Original design and print notes](https://learn.adafruit.com/case-for-circuit-playground).

**Relevance:** Particularly close to the user's proposed lip-and-snap arrangement. Locating overlap and shallow mating features offer a simpler benchmark than tall isolated catch stalks. Treat improved suitability as an engineering inference, not proof of a drop-in fix. These are releasable snap detents; the documentation does not establish a lock that can only be opened by pressing release tabs.

## Useful sliding mechanism, but not PLA evidence

Florian's TTGO T5 VPN controller is a real published ESP32 project with FreeCAD files. Its back lid slides and is locked by a pin; bending the lid outward releases that pin. Crucially, it was designed for **SLS PA12**, not PLA FDM. The creator also documents first-print problems: 0.5 mm clearances allowed the PCB to slide around, and added packing was required. It should not be presented as a proven no-rattle PLA solution. [Original repository and print feedback](https://github.com/flrs/vpn_remote_control_gadget), [editable CAD](https://github.com/flrs/vpn_remote_control_gadget/tree/main/cad/design).

**Relevance:** Demonstrates separation between a sliding cover and its release catch. For our case, a full-length sliding lid cannot retain the existing tall hold-down pillars unchanged: they would sweep across the board components. It would require separate fixed PCB retention or another closure path. That is our geometry assessment, not a claim from this maker.

## OpenSCAD reference: YAPP — Willem Aandewiel

YAPP uses an overlapping rim and bulges that engage lid openings. Inspection of `printSnapJoins()` in the downloaded `YAPPgenerator_v3.scad` confirms round or diamond-section features integrated into the shell, rather than our tall isolated tongues. The generator includes PCB locating pins and opposing lid supports. [Project and editable source](https://github.com/mrWheel/YAPP_Box), [snap geometry source](https://github.com/mrWheel/YAPP_Box/blob/main/YAPPgenerator_v3.scad).

The author's original article includes completed-print feedback from users, including a Wemos enclosure, but the reviewed reports do not establish PLA material or measured retention strength. This is a useful geometry reference, not proof of a positive press-to-release lock. [Author's explanation and reader reports](https://willem.aandewiel.nl/index.php/2022/01/02/yet-another-parametric-projectbox-generator/).

## A deliberately pull-off example

Philipp Schweizer's UNO Q enclosure is reported printed in PLA with four diamond-profile snaps and downloadable OpenSCAD files. Its instructions explicitly open it by pulling upward: both sides of the snaps are chamfered. That is useful evidence of a printable enclosure, but the intended release behaviour does not meet our wish for stronger retention requiring deliberate release. [Creator's build and downloads](https://raspberry.tips/en/3d-druck/arduino-uno-q-case-3d-printed).

## A useful independent follow-up on the lip approach

Probonopd's Onshape tutorial builds an overlapping shell with mating chamfered catches, acknowledges the Adafruit approach, and discusses clearance and retention angle separately. A reader reports that changing the angle to 33 degrees worked well for their enclosure. This is one person's feedback, not a general tolerance specification or a durability study. [Tutorial and discussion](https://gist.github.com/probonopd/5a3fa855498af0d3224c110723781efe).

## Recommendation for the next design decision

Use an overlapping lip with short, distributed snap features as the first geometry benchmark, with vertical assembly preserving the working PCB location and hold-down concept. Inspect actual source cross-sections before choosing dimensions. Retention must also be evaluated against the spring preload already present in this case; a generic storage-box detent may be too easy to pull open.

The PyGamer is the strongest comparable PLA build found in this pass. Its original model download was inaccessible during this research, so exact geometry has not been inspected. Its squeeze-opening instructions do not prove that straight pulling cannot also release it. A future adaptation should treat the base and lid as a matched pair; compatibility with the existing rigid base must not dictate another fragile tongue. Keep the physically successful board pegs and hold-down principle, and evaluate any next candidate as a full case with the PCB fitted, as the user requested.

Do not assume that deeper protrusions, a thicker root, or a watertight mesh prove a PLA latch will work. The makers above provide stronger evidence of printability than our new torsion-catch concept, but none establishes our required opening force or lifetime. If positive press-to-release locking is essential, a slide-and-stop design remains a candidate, with PCB retention redesigned explicitly rather than silently swept sideways.

No case geometry was modified during this research.

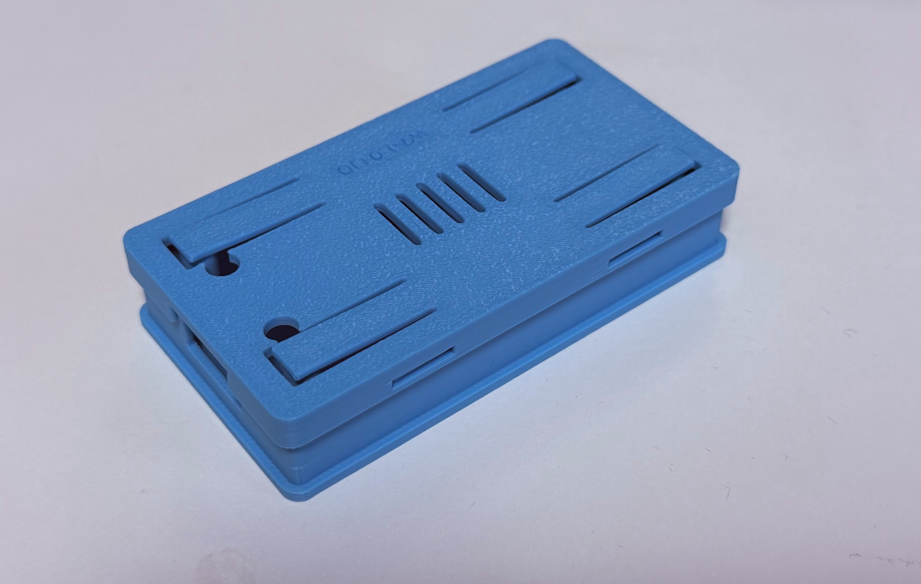
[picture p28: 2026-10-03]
hardware/wrover-case/makerworld/wrover-case-standalone/Pasted image (2).png

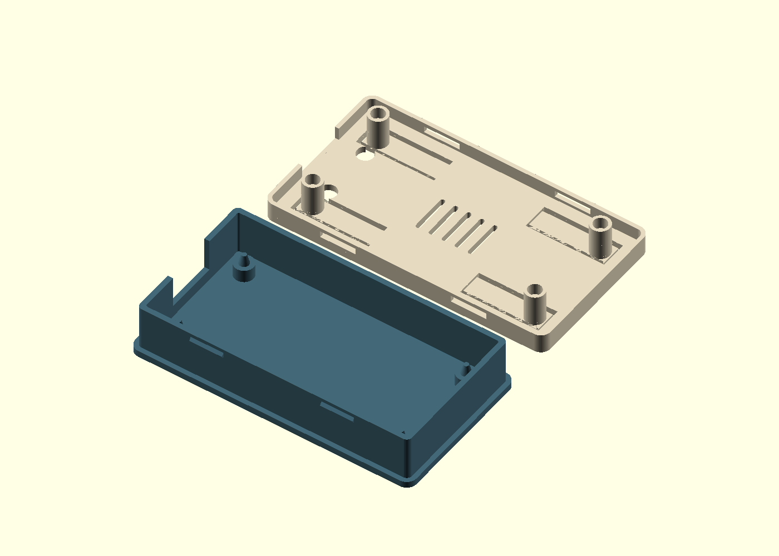
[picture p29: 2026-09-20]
hardware/wrover-case/makerworld/wrover-case-standalone/wrover-case-v7.1.0-layout.png

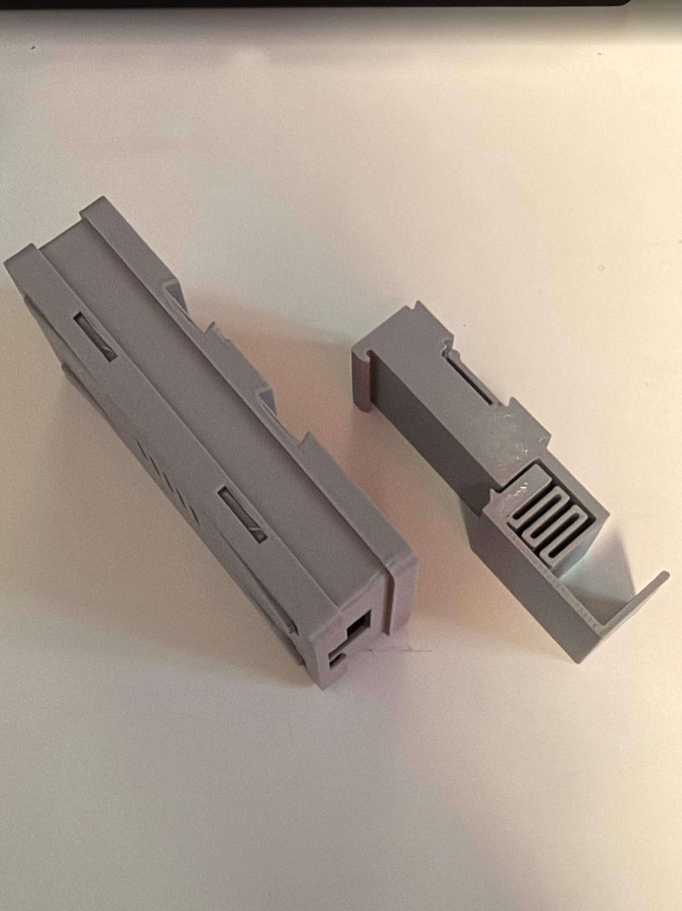
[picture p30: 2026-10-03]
hardware/wrover-case/makerworld/wrover-case-din-rail/Pasted image (2).png

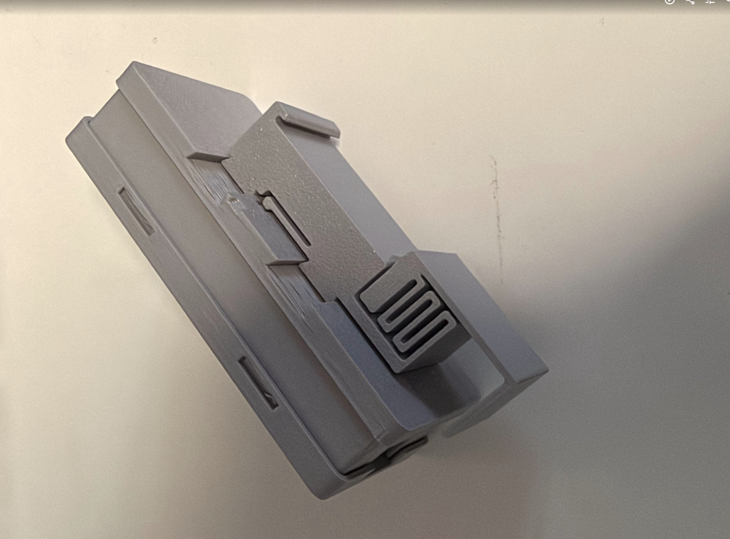
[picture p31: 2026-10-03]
hardware/wrover-case/makerworld/wrover-case-din-rail/Pasted image (3).png

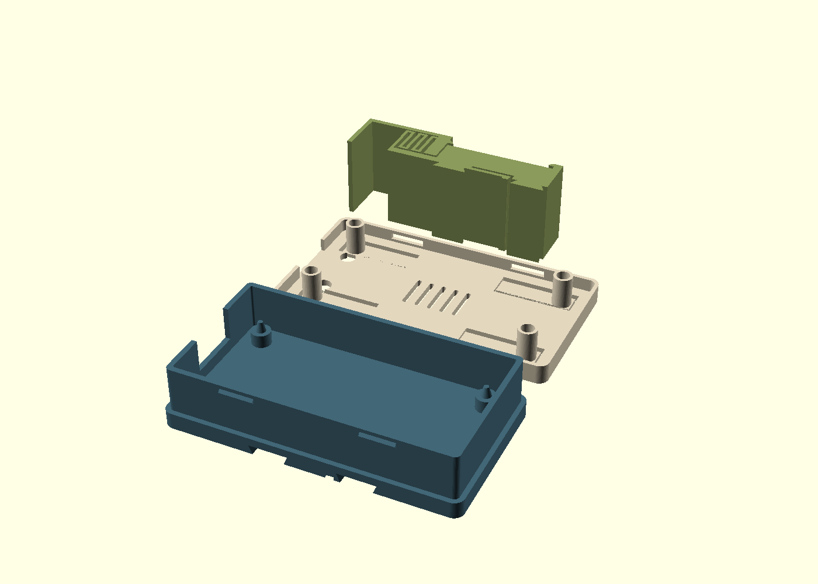
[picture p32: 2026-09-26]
hardware/wrover-case/makerworld/wrover-case-din-rail/wrover-case-v7.2.0-layout.png

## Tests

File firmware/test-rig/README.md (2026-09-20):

# Frozen test-phase firmware

Preserved v1.0 SS-TWR source for two Makerfabs ESP32 UWB DW3000 WROVER boards.
This is not the current custom MQTT/DS-TWR deployment firmware. Do not replace
an installed anchor/tag merely to reproduce a screenshot.

Provisioned binaries and raw calibration/capture files are local-only and
excluded from Git; build with your own ignored `src/secrets.h` copied from
`src/secrets.h.example`. Never distribute a binary with compiled-in credentials.

The test firmware supports initiator/responder roles, hostname, antenna delay,
interval and PHY stored in NVS. Its web UI and `/api/stats` expose live
diagnostics; this is not the deployment anchor API contract.

Historical test-rig interface

Toolchain pins are in `platformio.ini` and `VERSION`. Environment `uwb` builds
normal test firmware; `ota` supports wireless maintenance with explicitly
supplied private authentication; `nowifi` is a serial-only control build.
Uploading replaces the selected board's application.

Long (850 kbps / 1024-symbol preamble) and upright mounting worked well in the
tested pair. Antenna delay is setup-specific; neither board-pair calibration nor
range proves packaged-tag performance. See [findings](../../docs/findings.md).

Radio owns SPI on core 1; HTTP reads snapshots and OTA pauses the radio for flash
writes. The frozen protocol is unauthenticated SS-TWR, not deployment DS-TWR.

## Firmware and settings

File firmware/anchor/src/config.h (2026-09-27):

#pragma once
#include <Arduino.h>

// ---- Makerfabs ESP32 UWB DW3000 (WROVER) pin map ----
#define PIN_RST 27
#define PIN_IRQ 34
#define PIN_SS  4

// ---- Frame layout (from the Makerfabs / Qorvo SS-TWR example) ----
#define ALL_MSG_COMMON_LEN      10
#define ALL_MSG_SN_IDX          2
#define RESP_MSG_POLL_RX_TS_IDX 10
#define RESP_MSG_RESP_TX_TS_IDX 14
#define RESP_MSG_TS_LEN         4

// ---- PHY profiles ----
// SHORT is the vendor example: 128 symbol preamble at 6.8 Mbps. It is the
// shortest-range configuration the part offers.
// LONG trades data rate for link budget: 1024 symbol preamble at 850 kbps,
// worth roughly 15-18 dB, at the cost of a much longer frame.
// MAX pushes the preamble to 2048 symbols for another ~3 dB over LONG, at the
// cost of roughly 9 ms of air time per exchange.
enum Phy : uint8_t { PHY_SHORT = 0, PHY_LONG = 1, PHY_MAX = 2, PHY_COUNT };

// Timing must follow the profile. The radio schedules the preamble so the
// RMARKER lands at the programmed instant, so the responder's turnaround has
// to exceed the preamble duration (~1016 uus at PLEN_1024) or the delayed
// transmit is already in the past and fails.
struct PhyTiming {
  uint16_t poll_tx_to_resp_rx_dly;
  uint16_t resp_rx_timeout;
  uint16_t poll_rx_to_resp_tx_dly;
};
static const PhyTiming PHY_TIMING[PHY_COUNT] = {
  {600,   400,  900},   // SHORT: preamble ~127 uus
  {100,  6000, 3000},   // LONG:  preamble ~1016 uus, turnaround must exceed it
  {100, 12000, 4000},   // MAX:   preamble ~2032 uus
};
// Bounded RX window so the ranging task periodically yields to the idle task
// instead of spinning forever (the stock example spins with no timeout).
#define RESPONDER_RX_WINDOW_UUS    60000

// ---- DS-TWR ----
#define FN_POLL  0x21
#define FN_RESP  0x10
#define FN_FINAL 0x23
#define FINAL_MSG_POLL_TX_TS_IDX  10
#define FINAL_MSG_RESP_RX_TS_IDX  14
#define FINAL_MSG_FINAL_TX_TS_IDX 18
#define FINAL_MSG_BATT_MV_IDX     22
#define FINAL_MSG_FLAGS_IDX       24
#define FINAL_MSG_MISSES_IDX      25
#define FINAL_MSG_WAKE_COUNT_IDX  27
#define FINAL_FLAG_MOVING         0x01
#define FINAL_FLAG_SENSOR_FAULT   0x02
#define FINAL_LEN_LEGACY          24
#define FINAL_LEN_WITH_BATT       26
#define FINAL_LEN_WITH_TELEMETRY  29
#define FINAL_LEN_WITH_WAKE_COUNT 33
#define FINAL_LEN_WITH_TIP        41

// A tag that reports itself moving is expected to report often, so silence
// means a lost link rather than a bin that has not moved. Without this, a
// dropout mid-collection is indistinguishable from a parked bin.
#define MOVING_STALE_S 20

// Open the FINAL receive window early: its preamble starts ~1016 uus before
// the programmed RMARKER on the Long profile.
#define RESP_TX_TO_FINAL_RX_DLY_UUS 100
#define FINAL_RX_TIMEOUT_UUS        8000

// ---- Anchor identity ----
#define ANCHOR_ADDR   0x4157        // 'W','A'
#define ANCHOR_ID     "a"
// Default liveness threshold. A motion-woken tag is silent because it has not
// moved, not because it is broken, so this must be generous - several times
// the tag's idle tick. Overridable per tag in the adoption record.
#define DEFAULT_STALE_AFTER_S 21600   // 6 hours
#define BURST_IDLE_MS 1500          // a burst has ended after this much quiet

// Defaults; antenna delay is runtime-tunable and persisted in NVS.
#define DEFAULT_ANT_DLY      16356

// Rolling window used for the live statistics and the chart.
#define STATS_WINDOW 256
#define CHART_POINTS 120

#include "core/tagstats.h"
// One completed exchange, handed from the radio task to core 0.
struct RangeEvent {
    uint16_t addr;
    RangeSample sample;
    uint32_t at_ms;
    uint16_t batt_mv;   // 0 explicitly means unknown
    uint16_t misses;    // cumulative failed local exchanges since tag boot
    uint32_t wake_count; // diagnostic only; resets when the tag reboots
    bool moving;        // the tag's own motion state
    bool sensor_fault;
    bool has_battery;   // includes the older battery-only 26-byte layout
    bool has_telemetry; // 29-byte telemetry (or newer) was present
    bool has_wake_count;
    bool has_tip;
    bool tip_ready;
    uint32_t tip_count;
    uint32_t tip_age_s;
};

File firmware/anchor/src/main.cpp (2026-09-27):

#include <Arduino.h>
#include <WiFi.h>
#include <ESPmDNS.h>
#include <ArduinoOTA.h>
#include "secrets.h"
#include "config.h"
#include "ranging.h"
#include "stats.h"
#include "webui.h"
#include "mqttlink.h"
#include "publisher.h"
#include "admin.h"
#include "tag_updater.h"
#include "update_mqtt.h"
#include "motion_mqtt.h"

static void wifi_connect() {
  WiFi.mode(WIFI_STA);
  WiFi.setHostname(webui_hostname().c_str());
  // ESP-IDF 4.4 coexistence aborts when BLE starts with WIFI_PS_NONE.
  // Modem sleep lets the shared 2.4 GHz radio schedule Wi-Fi alongside BLE.
  WiFi.setSleep(WIFI_PS_MIN_MODEM);
  WiFi.setAutoReconnect(true);
  WiFi.begin(WIFI_SSID, WIFI_PASS);

  Serial.printf("[wifi] joining %s", WIFI_SSID);
  uint32_t giveup = millis() + 20000;
  while (WiFi.status() != WL_CONNECTED && millis() < giveup) {
    delay(250);
    Serial.print(".");
  }
  Serial.println();

  if (WiFi.status() == WL_CONNECTED) {
    Serial.printf("[wifi] %s  http://%s/  (http://%s.local/)\n",
                  WiFi.localIP().toString().c_str(),
                  WiFi.localIP().toString().c_str(),
                  webui_hostname().c_str());
  } else {
    // Ranging is the point of the board; it must not depend on the network.
    Serial.println("[wifi] not connected — ranging continues, will retry in background");
  }
}

static void ota_begin() {
  if (!admin_configured()) return;
  ArduinoOTA.setHostname(webui_hostname().c_str());
  ArduinoOTA.setMdnsEnabled(false);  // HTTP owns the shared mDNS responder.
  admin_apply_ota_credentials();
  ArduinoOTA.onStart([] {
    Serial.println("[ota] starting — suspending radio");
    ranging_suspend();
  });
  ArduinoOTA.onEnd([] { Serial.println("\n[ota] done"); });
  ArduinoOTA.onProgress([](unsigned p, unsigned t) {
    Serial.printf("[ota] %u%%\r", (p * 100) / t);
  });
  ArduinoOTA.onError([](ota_error_t e) {
    Serial.printf("[ota] error %u — resuming radio\n", e);
    ranging_resume();
  });
  ArduinoOTA.begin();
}

void setup() {
  Serial.begin(115200);
  delay(200);
  Serial.println("\n=== BinRange anchor ===");

  stats_init();
  webui_load_prefs();     // hostname must be known before Wi-Fi starts
  ranging_init();         // bring up the radio, but do not start ranging yet

  wifi_connect();
  // Wall-clock time, so "last seen" can be a real timestamp in Home
  // Assistant rather than an uptime counter.
  configTime(0, 0, "pool.ntp.org", "time.cloudflare.com");
  mqtt_begin();
  publisher_begin();
  tag_updater_begin();
  webui_begin();          // TCP/IP stack is up now
  if (MDNS.begin(webui_hostname().c_str())) MDNS.addService("http", "tcp", 80);
  ota_begin();

  Serial.printf("[sys] role=RESPONDER antdly=%u free heap=%u\n",
                ranging_antdly(), ESP.getFreeHeap());
}

// Ranging starts only once MQTT has connected, so retained tag adoptions have
// arrived before the first exchange. Without this the queue fills during the
// Wi-Fi connect with nothing draining it, and adopted tags are briefly counted
// as unknown. The timeout guarantees ranging never depends on the broker.
#define RADIO_START_TIMEOUT_MS 15000
// Connecting is not the same as having received retained messages: the broker
// delivers those over the following loop iterations. Wait a moment after the
// connection so adoptions land before the first exchange.
#define RETAINED_SETTLE_MS 1500
static bool radio_started;
static uint32_t connected_since;

static void maybe_start_radio() {
    if (radio_started) return;
    if (mqtt_connected() && !connected_since) connected_since = millis();
    if (!mqtt_connected()) connected_since = 0;

    bool settled = connected_since && (millis() - connected_since > RETAINED_SETTLE_MS);
    if (settled || millis() > RADIO_START_TIMEOUT_MS) {
        radio_started = true;
        ranging_start();
        Serial.printf("[sys] ranging started (%s)\n",
                      settled ? "broker connected, retained messages settled"
                              : "broker timeout, starting anyway");
    }
}

void loop() {
  // Core 0: network only. The radio never waits on any of this.
  // A second firmware writer must not interrupt an owned tag BLE session.
  if (!tag_updater_busy()) ArduinoOTA.handle();
  webui_loop();
  mqtt_loop();
  maybe_start_radio();
  publisher_loop();
  tag_updater_loop();
  update_mqtt_loop();
  motion_mqtt_loop();

  static uint32_t last_try = 0;
  if (WiFi.status() != WL_CONNECTED && millis() - last_try > 15000) {
    last_try = millis();
    WiFi.reconnect();
  }
  delay(2);
}

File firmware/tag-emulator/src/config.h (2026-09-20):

#pragma once
#include <Arduino.h>

// ---- Makerfabs ESP32 UWB DW3000 (WROVER) pin map ----
#define PIN_RST 27
#define PIN_IRQ 34
#define PIN_SS  4

// ---- Roles ----
enum Role : uint8_t { ROLE_INITIATOR = 0, ROLE_RESPONDER = 1 };

// ---- Frame layout (from the Makerfabs / Qorvo SS-TWR example) ----
#define ALL_MSG_COMMON_LEN      10
#define ALL_MSG_SN_IDX          2
#define RESP_MSG_POLL_RX_TS_IDX 10
#define RESP_MSG_RESP_TX_TS_IDX 14
#define RESP_MSG_TS_LEN         4

// ---- PHY profiles ----
// SHORT is the vendor example: 128 symbol preamble at 6.8 Mbps. It is the
// shortest-range configuration the part offers.
// LONG trades data rate for link budget: 1024 symbol preamble at 850 kbps,
// worth roughly 15-18 dB, at the cost of a much longer frame.
// MAX pushes the preamble to 2048 symbols for another ~3 dB over LONG, at the
// cost of roughly 9 ms of air time per exchange.
enum Phy : uint8_t { PHY_SHORT = 0, PHY_LONG = 1, PHY_MAX = 2, PHY_COUNT };

// Timing must follow the profile. The radio schedules the preamble so the
// RMARKER lands at the programmed instant, so the responder's turnaround has
// to exceed the preamble duration (~1016 uus at PLEN_1024) or the delayed
// transmit is already in the past and fails.
struct PhyTiming {
  uint16_t poll_tx_to_resp_rx_dly;
  uint16_t resp_rx_timeout;
  uint16_t poll_rx_to_resp_tx_dly;
};
static const PhyTiming PHY_TIMING[PHY_COUNT] = {
  {600,   400,  900},   // SHORT: preamble ~127 uus
  {100,  6000, 3000},   // LONG:  preamble ~1016 uus, turnaround must exceed it
  {100, 12000, 4000},   // MAX:   preamble ~2032 uus
};
// Bounded RX window so the ranging task periodically yields to the idle task
// instead of spinning forever (the stock example spins with no timeout).
#define RESPONDER_RX_WINDOW_UUS    60000

// ---- DS-TWR ----
// Three messages: POLL (tag) -> RESP (anchor) -> FINAL (tag, carrying the
// tag's three timestamps so the anchor can compute the range).
#define FN_POLL  0x21
#define FN_RESP  0x10
#define FN_FINAL 0x23
#define FINAL_MSG_POLL_TX_TS_IDX  10
#define FINAL_MSG_RESP_RX_TS_IDX  14
#define FINAL_MSG_FINAL_TX_TS_IDX 18
// The tag reports its battery inside FINAL, so the anchor learns it as part of
// ranging rather than needing a channel of its own. Two bytes, millivolts,
// little endian. A 24 byte FINAL without them stays valid.
#define FINAL_MSG_BATT_MV_IDX     22
// Telemetry the anchor cannot observe for itself. Misses are failed polls
// since the last success: the anchor never hears those, so without this its
// success rate is measured over a denominator that excludes every failure.
#define FINAL_MSG_FLAGS_IDX       24   // bit 0: tag reports itself moving
#define FINAL_MSG_MISSES_IDX      25   // uint16 LE, saturating
#define FINAL_FLAG_MOVING         0x01

// Both turnarounds must exceed the preamble duration (~1016 uus on the Long
// profile) or the delayed transmit is already in the past and fails.
#define RESP_RX_AFTER_TX_DLY_UUS    100
#define RESP_RX_TIMEOUT_DS_UUS      6000
#define RESP_RX_TO_FINAL_TX_DLY_UUS 3000

// ---- Tag emulation ----
// A real bin tag wakes, ranges a few times and sleeps; it does not free-run.
// The anchor's queue and publication path must see that intermittency.
#define DEFAULT_TAG_ADDR   0x4556   // 'V','E'
#define DEFAULT_BURST_SIZE 8
#define DEFAULT_EVENT_MS   10000

// The emulator can impersonate several tags in turn, one burst per identity.
// This exercises the anchor's registry, per-tag statistics and per-tag burst
// detection. It does NOT test concurrency: there is still only one radio, so
// transmissions never overlap and the anchor's interleaved-FINAL guard is
// never reached.
#define MAX_TAG_IDS 8

// Motion model. A real tag sleeps until its accelerometer interrupt fires,
// ranges quickly while moving, then falls back to a slow liveness tick. Each
// identity has its own state, so one bin can be wheeled out while the rest sit
// still - which is what the anchor will actually see.
#define DEFAULT_MOTION_TICK_MS 5000     // while moving
#define DEFAULT_IDLE_TICK_MS   60000    // liveness only; 600000 in the field
#define DEFAULT_MOTION_HOLD_MS 60000    // how long motion persists after a trigger

// Simulated CR2477. Real discharge would take years, so a drain multiplier
// accelerates it for testing; 1 means real time.
#define BATT_CAPACITY_UAH   700000.0f   // 700 mAh usable
#define BATT_UAH_PER_EXCH   0.4f        // measured estimate for one DS-TWR exchange
// At the 60 s idle tick with 16 exchange bursts, real drain is ~9 mAh/day, so
// a real cell lasts months and shows nothing on a bench. 200x drains a
// simulated 700 mAh in roughly nine hours: visible across a working session
// without vanishing before you can watch it. 1 is real time.
#define DEFAULT_DRAIN_MULT  200

// Defaults; antenna delay is runtime-tunable and persisted in NVS.
#define DEFAULT_ANT_DLY      16356
#define DEFAULT_INTERVAL_MS  100

// Rolling window used for the live statistics and the chart.
#define STATS_WINDOW 256
#define CHART_POINTS 120

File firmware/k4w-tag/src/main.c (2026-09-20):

/* Bench diagnostic: no radio TX, no flash/UICR writes, no BLE yet. */
#include <zephyr/kernel.h>
#include <zephyr/drivers/gpio.h>
#include <zephyr/drivers/spi.h>
#include <zephyr/sys/byteorder.h>

/* Locate with nm, inspect via SWD. Phase 3 means SPI reads are running;
 * it is not a claim that radio initialization or ranging has succeeded. */
volatile struct {
    uint32_t magic;
    uint32_t phase;
    int32_t error;
    uint32_t radio_id;
    uint32_t reads;
} tag_diag = { .magic = 0x42524447 };

static const struct spi_dt_spec radio =
    SPI_DT_SPEC_GET(DT_NODELABEL(uwb), SPI_WORD_SET(8) | SPI_TRANSFER_MSB, 0);
static const struct gpio_dt_spec reset =
    GPIO_DT_SPEC_GET(DT_NODELABEL(uwb), reset_gpios);

int main(void)
{
    tag_diag.phase = 1;
    if (!spi_is_ready_dt(&radio) || !gpio_is_ready_dt(&reset)) {
        tag_diag.error = -ENODEV;
        return 0;
    }
    /* Assert active-low reset, then RELEASE it; do not drive RSTn high. */
    int rc = gpio_pin_configure_dt(&reset, GPIO_OUTPUT_ACTIVE);
    if (rc) { tag_diag.error = rc; return 0; }
    k_msleep(2);
    rc = gpio_pin_configure_dt(&reset, GPIO_INPUT);
    if (rc) { tag_diag.error = rc; return 0; }
    k_msleep(10);
    tag_diag.phase = 2;
    while (true) {
        uint8_t tx[5] = {0}; /* Fast-access read, register file 0, offset 0. */
        uint8_t rx[5] = {0};
        struct spi_buf tx_buf = {.buf = tx, .len = sizeof(tx)};
        struct spi_buf rx_buf = {.buf = rx, .len = sizeof(rx)};
        struct spi_buf_set tx_set = {.buffers = &tx_buf, .count = 1};
        struct spi_buf_set rx_set = {.buffers = &rx_buf, .count = 1};
        rc = spi_transceive_dt(&radio, &tx_set, &rx_set);
        tag_diag.error = rc;
        if (!rc) {
            tag_diag.radio_id = sys_get_le32(rx + 1);
            tag_diag.reads++;
        }
        tag_diag.phase = 3;
        k_msleep(1000);
    }
}

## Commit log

2026-09-20 Add working WROVER case v7.1.0 and versioned prototype history
    [makerfabs-esp32-uwb-v1.brd, verify_geometry.scad, wrover-case-v2.0.0-base.stl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]
2026-09-26 Add experimental WROVER case v7.2.0 with snap-on DIN rail mount
    v7.1.0 base on a 3 mm dovetail plinth plus a separate TS35 clip that
    snaps on mid-rail (fixed hook, serpentine-sprung latch, pull tab).
    Lid reused byte-identical. Adds DIN and mid-rail tilt geometry checks.
    [verify_geometry.scad, wrover-case-v7.2.0-base.stl, wrover-case-v7.2.0-din-clip.stl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]
2026-09-26 Add case renders and sanitized hardware photos to README
2026-09-27 Add calibrated tipping events and grouped emptying notifications
2026-10-03 Add MakerWorld case packages and 3MF builder
    [wrover-case-din-rail-v7.2.0.3mf, wrover-case-standalone-v7.1.0.3mf, wrover-case-v7.1.0-base.stl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]
